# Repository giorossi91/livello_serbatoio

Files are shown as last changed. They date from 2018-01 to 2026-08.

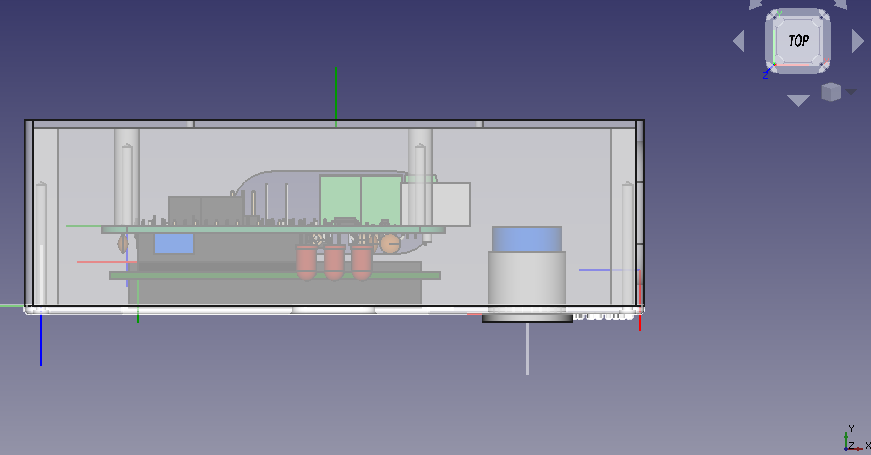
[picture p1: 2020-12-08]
schemi/scheda_definitiva/immagini/box_top.png

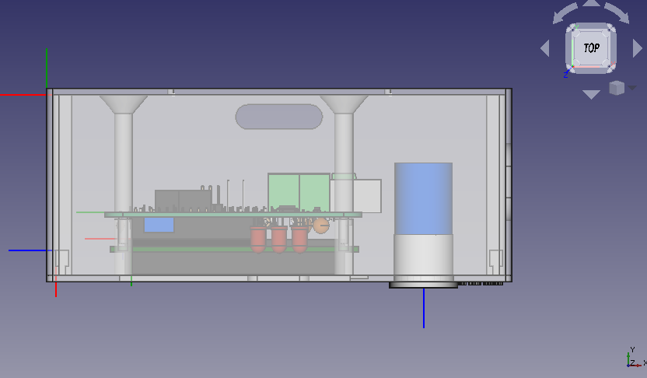
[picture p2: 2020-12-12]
schemi/box/senza_viti/img_senza_viti/box_top.png

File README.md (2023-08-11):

# Tank level monitor

## Scope
This project realizes a simple device to monitor the water level in a tank.

## Architecture
The monitor is realized with an ATMEGA328P microcontroller to run the SW produced with Arduino IDE environment, an ultrasonic sensor to measure the level of the water and an LCD 16x2 characters to show the liters amount associated to the percentage of filling.

## Sofware
The SW has been developed with Arduino IDE and tested with CppUnit and a Qt GUI used to simulate the external environment.

## Phases of the project
### Phase 1 (Prototype)
The project was realized on a prototype board using the schematic in `schemi\schema_scheda.pdf`. The microcontroller was hosted in an Arduino UNO rev3 board.
The schematic was realized with Fritzing. The enclosure was hand-made and adapted from an existing one.

### Phase 2 (Finished)
The entire schematic was re-designed with Kicad and a PCB has been designed and produced. The enclosure has been designed with Freecad and 3D printed.

## Project Website
Go to [project website](https://giorossi91.github.io/livello_serbatoio)

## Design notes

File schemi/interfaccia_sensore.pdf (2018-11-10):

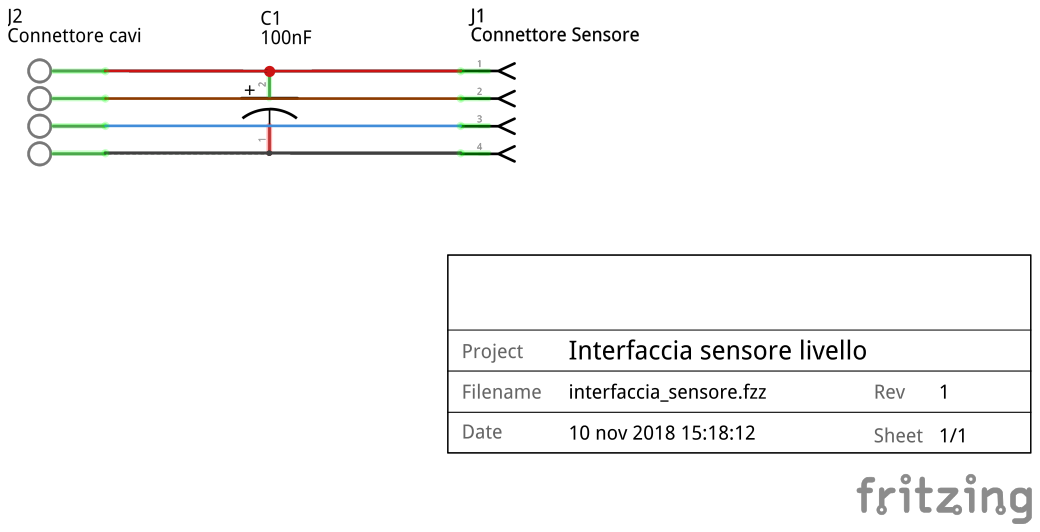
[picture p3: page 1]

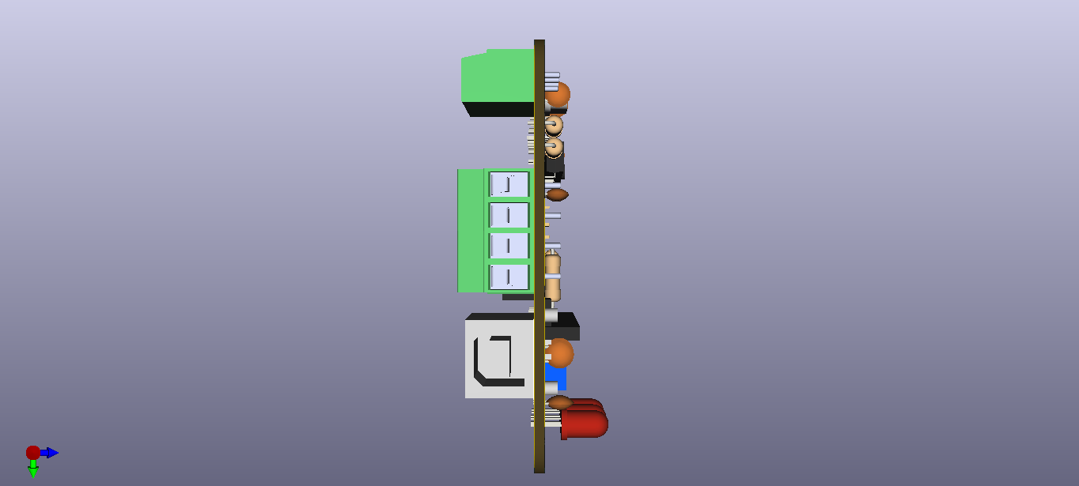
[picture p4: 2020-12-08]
schemi/scheda_definitiva/immagini/scheda_right.png

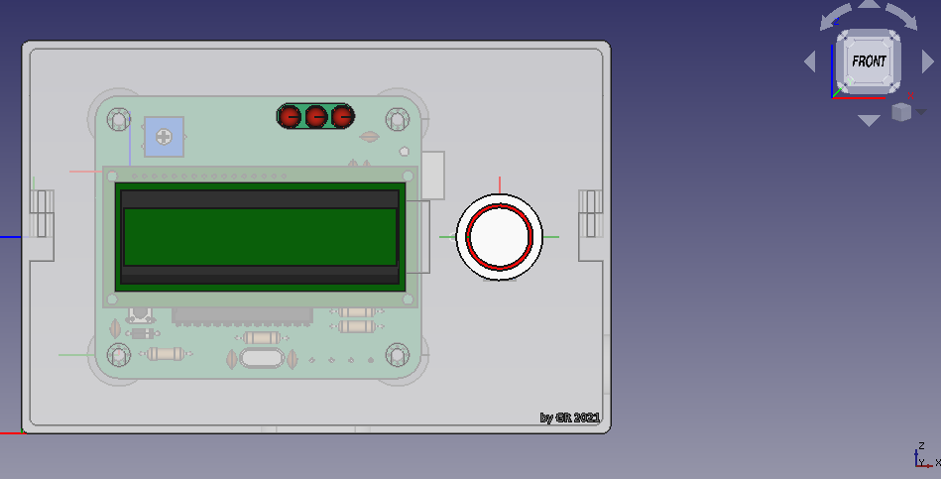
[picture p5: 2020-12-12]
schemi/box/senza_viti/img_senza_viti/box_front.png

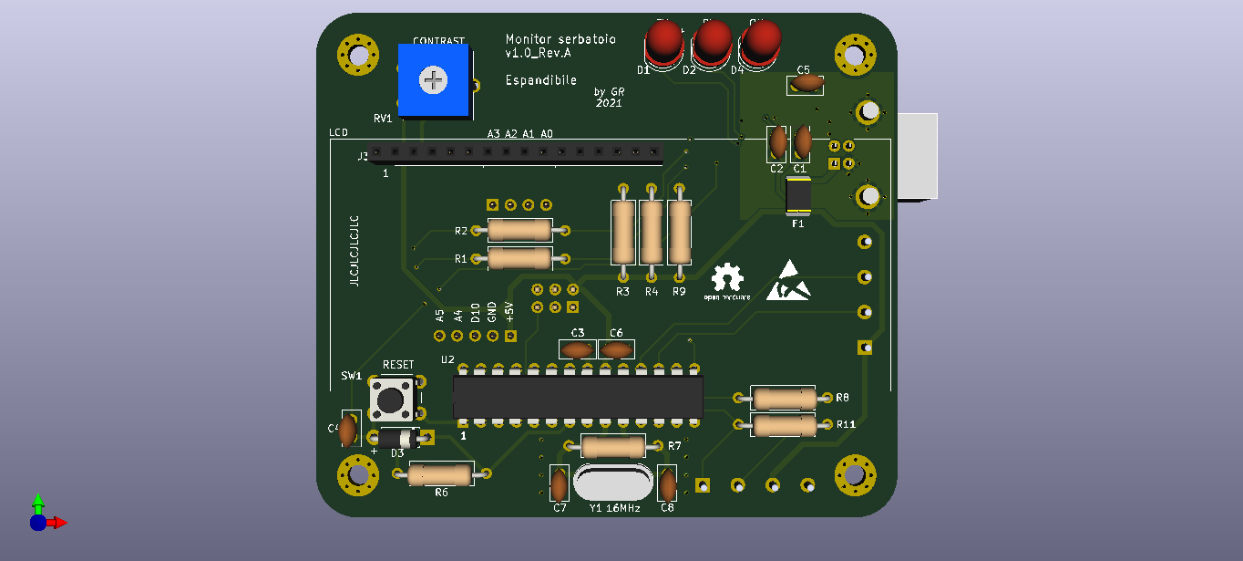
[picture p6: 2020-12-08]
schemi/scheda_definitiva/immagini/scheda_top.png

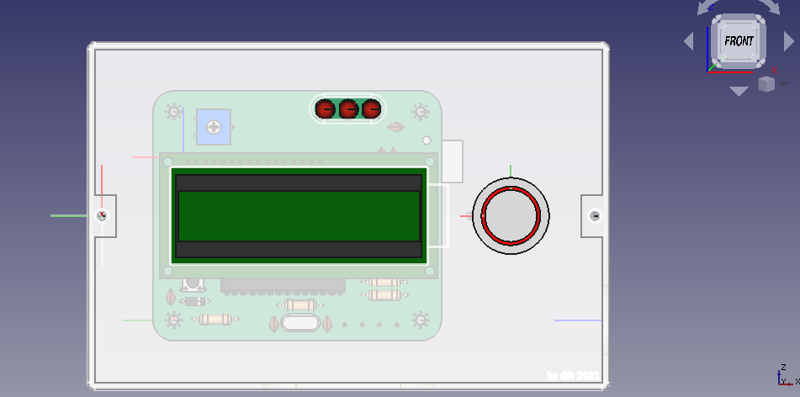
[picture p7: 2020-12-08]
schemi/scheda_definitiva/immagini/box_front.png

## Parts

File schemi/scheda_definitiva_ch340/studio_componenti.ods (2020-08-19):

Nome | Descrizione | Formato | Fornitore | Prezzo | Link | Note
FT232RL-REEL | Bridge Interfaccia, Da USB a UART, 1.8 V, 5.25 V, SSOP, 28 Pin, -40 °C | SSOP, 28 pin | Farnell | € 4,25 | https://it.farnell.com/ftdi/ft232rl-reel/ic-da-usb-a-uart-smd-28ssop/dp/1146032?st=ft232rl
ATMEGA328-PU | Microcontrollore a 8 bit, microcontrollori famiglia AVR ATmega, serie ATmega328, 20MHz, 1KB, 32KB | 28 PDIP | Farnell | € 1,70 | https://it.farnell.com/microchip/atmega328-pu/mcu-8bit-atmega-20mhz-dip-28/dp/1972087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
AS-16.000-18 | Cristallo, 16 MHz, Foro Passante, 10,3mm x 5mm, 50 ppm, 18 pF, 30 ppm, Serie AS | 5mm, foro passante 2 pin | Farnell | € 0,247 | https://it.farnell.com/raltron/as-16-000-18/cristallo-16mhz-18pf-hc-49s/dp/1611761?pf=412004278%2C412016994
1N4148TR | Diodo Piccolo Segnale, Singolo, 100 V, 150 mA, 1 V, 4 ns, 2 A | foro passante | Farnell | € 0,07 | https://it.farnell.com/vishay/1n4148tr/diodo-piccolo-segn-singolo-100v/dp/1469384
USB-B-S-RA | Connettore USB, USB Tipo B, USB 2.0, Presa, 4 Vie, Montaggio su Foro Passante, Angolo Retto | foro passante | Farnell | € 0,46 | https://it.farnell.com/multicomp/usb-b-s-ra/usb-2-0-tipo-b-presa-th/dp/2112373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
0473.500HAT1L | Fusibile, Cavo PCB, 500 mA, 125 V, PICO II 473 Series, 125 V, Azione Lenta, Conduttori Assiali | foro passante | Farnell | € 2,38 | https://it.farnell.com/littelfuse/0473-500hat1l/fusibile-assiale-0-5a-colpo-lento/dp/2723068?st=fuse
2227MC-28-03-05-F1 | Presa per CI e Componente, 28 Contatti, Presa DIP, 2.54 mm, Serie 2227MC, 7.62 mm, Bronzo Fosforoso | foro passante | Farnell | € 0,76 | https://it.farnell.com/multicomp/2227mc-28-03-05-f1/socket-ic-dil-0-3-28-vie/dp/1103850?MER=sy-me-pd-mi-alte

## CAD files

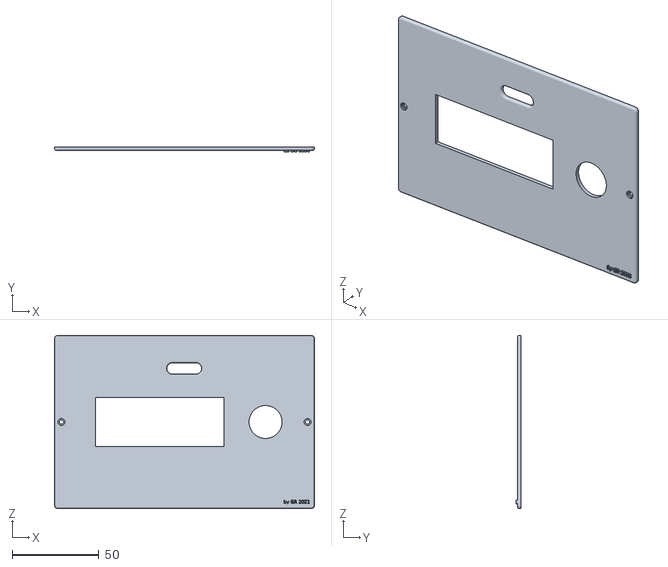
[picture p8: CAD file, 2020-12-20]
schemi/box/con_viti/coperchio_print.stl
150.0 x 3.00 x 100.0

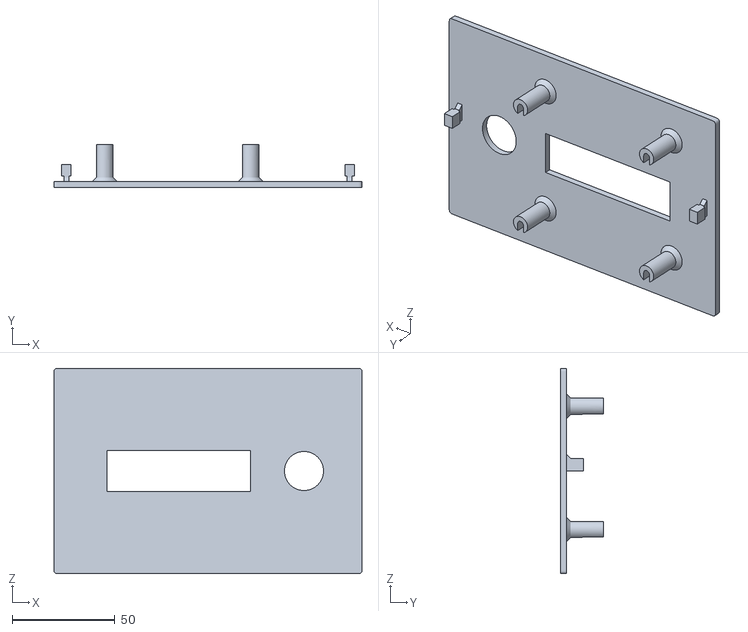
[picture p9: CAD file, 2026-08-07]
schemi/box/fusion360/Coperchio.stl
150.0 x 21.0 x 100.0

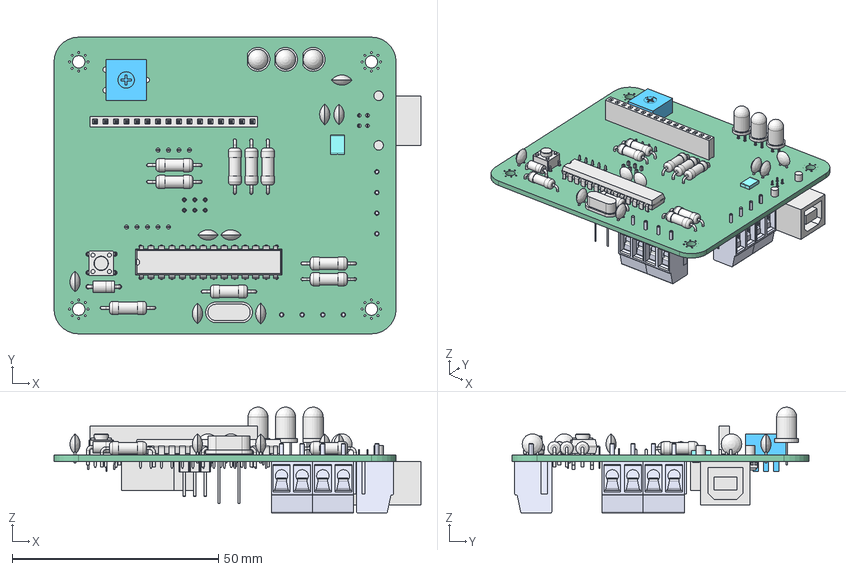
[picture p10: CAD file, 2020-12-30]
schemi/box/test_assembly_espansione/pcb_board.FCStd
89.0 x 72.0 x 25.7 mm
Pcb_8929
SW1_SW_PUSH_6mm_h5mm_5FCE63C8
RV1_ACP470_5F3BE09B x 2
D4_LED_D5.0mm_5FA6C0E4 x 3
F1_MF-MSMF050_5FB19120[2] x 2
D3_D_DO-41_SOD81_P7.62mm_Horizontal_5FCE6338
C5_C_Disc_D50mm_W25mm_P250mm_5FB07593 x 8
Y1_Crystal_5F93F8CD
U2_DIP-28_W7.62mm_5F8B1761
J3_PinSocket_1x16_P254mm_Vertical_5FB99047
R1_R_Axial_DIN0309_L90mm_D32mm_P1270mm_Horizontal_5FCA8AFD x 9
J6_PinSocket_1x04_P254mm_Vertical_5FCA8662
J7_PinSocket_1x05_P254mm_Vertical_5FC31174
U3_SOT_23_6_5FB065DB
TB001-500-02P_Green - P x 2
TB001-500-02P_Green - P001 x 2
J1_usb_b_conn_5FA8DFDA[2]
U1_SSOP_28_53x102mm_P065mm_5FB0862F
J5_PinHeader_2x03_P254mm_Vertical_5FA86B0F

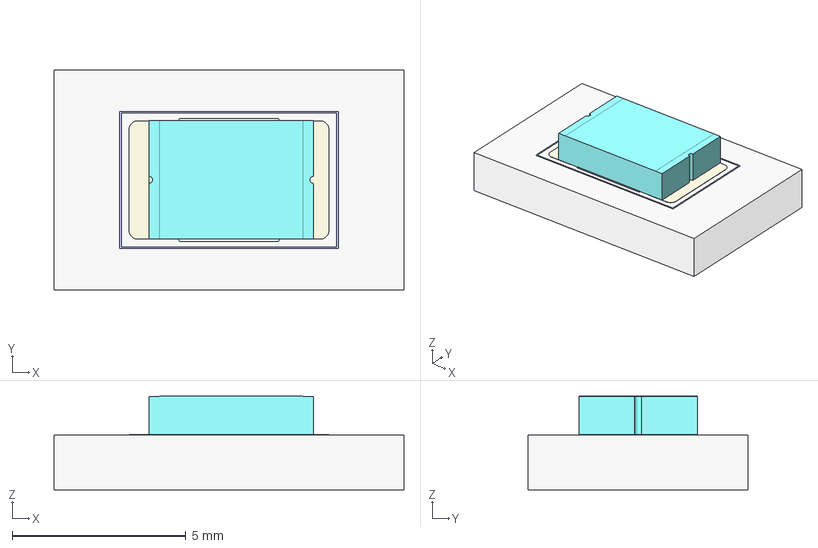
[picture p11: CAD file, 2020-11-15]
schemi/scheda_definitiva_ch340/3d_component/MF-MSMF050-2.FCStd
10.1 x 6.32 x 2.69 mm
FCrtYd
FFab
FrontSilk
TopPads
Pcb
MF-MSMF050

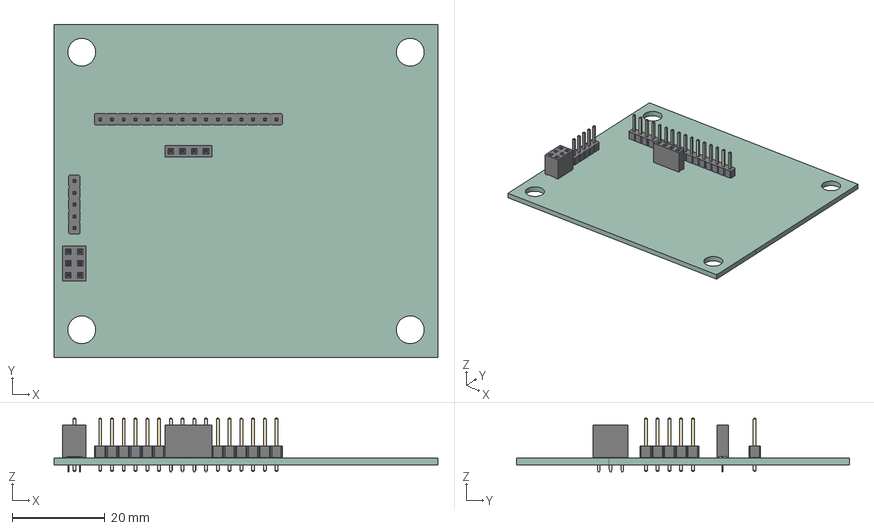
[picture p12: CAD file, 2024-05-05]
schemi/scheda_espansione/livello_serbatoio_espansione/livello_serbatoio_espansione.step
83.0 x 72.0 x 11.6 mm
PinSocket_2x03_P254mm_Vertical
PinHeader_1x16_P254mm_Vertical
PinHeader_1x05_P254mm_Vertical
PinSocket_1x04_P254mm_Vertical
livello_serbatoio_espansione_PCB

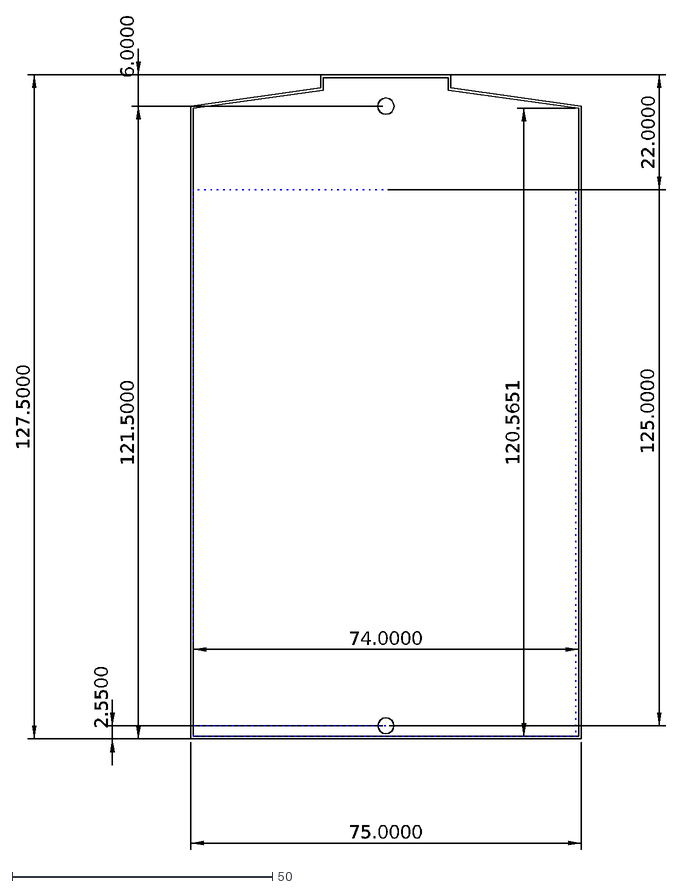
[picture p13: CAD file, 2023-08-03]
schemi/serbatoio.dxf
127.5000
121.5000
6.0000
2.5500
75.0000
120.5651
22.0000
74.0000
125.0000

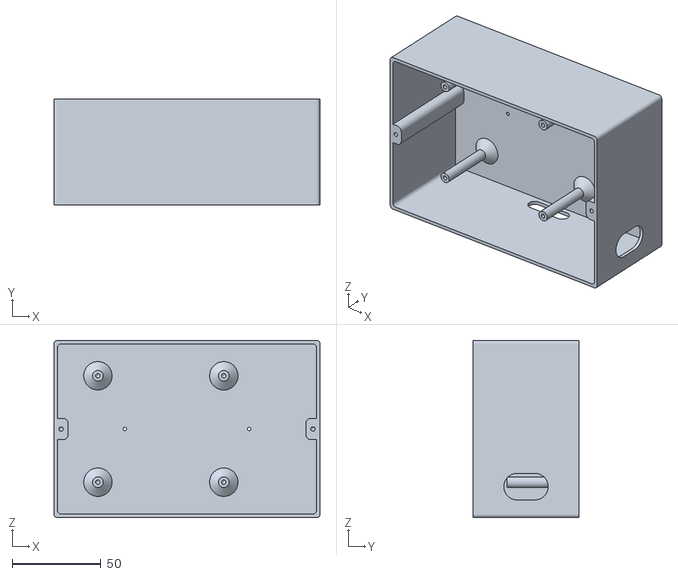
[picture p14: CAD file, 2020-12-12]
schemi/box/con_viti/box_print.stl
150.0 x 60.0 x 100.0

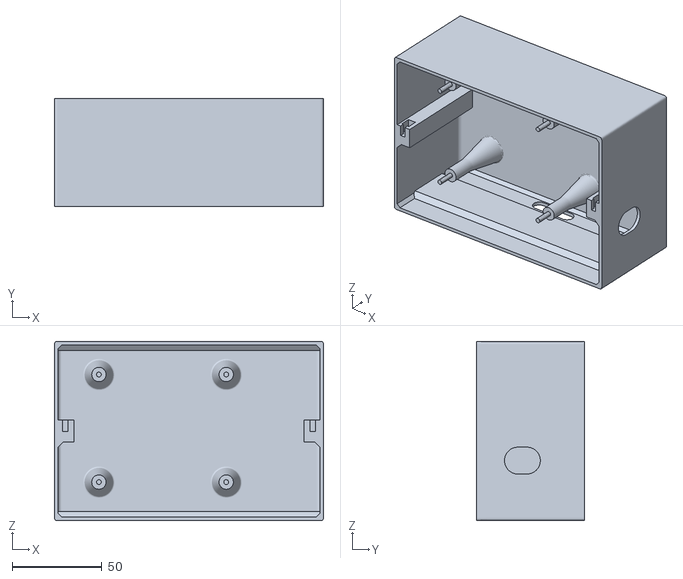
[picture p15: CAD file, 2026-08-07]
schemi/box/fusion360/Case.stl
150.0 x 60.0 x 100.0

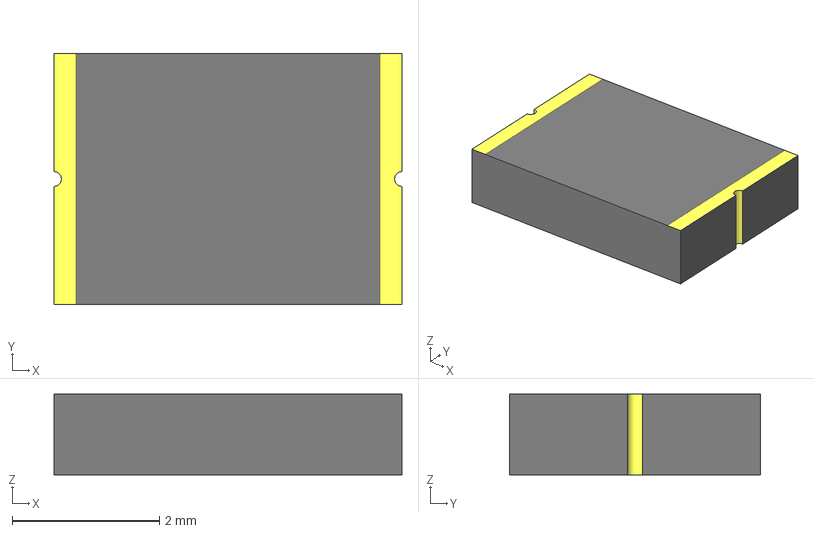
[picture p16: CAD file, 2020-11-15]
schemi/scheda_definitiva_ch340/3d_component/MF-MSMF050.step
4.73 x 3.41 x 1.10 mm

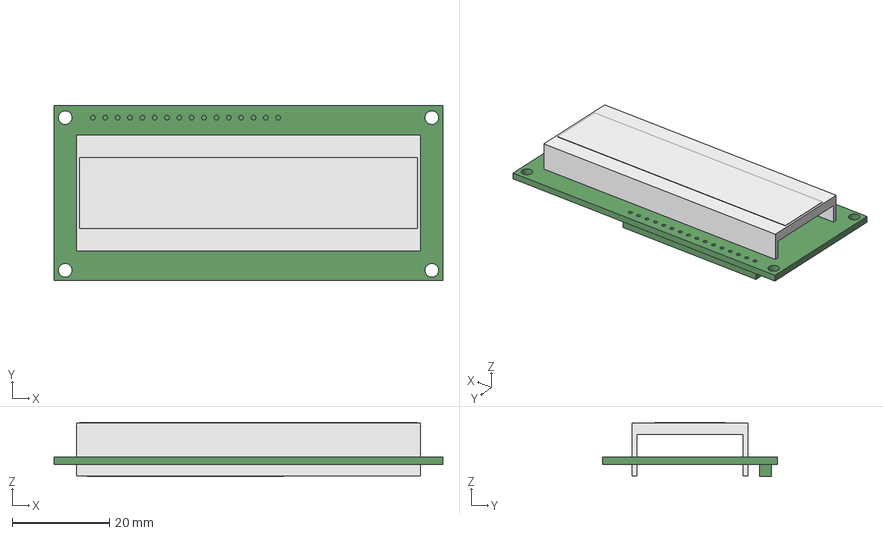
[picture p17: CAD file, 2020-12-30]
schemi/box/test_assembly_espansione/lcd.FCStd
80.0 x 36.0 x 11.2 mm
corpo_lcd
pcb
BooleanFragments

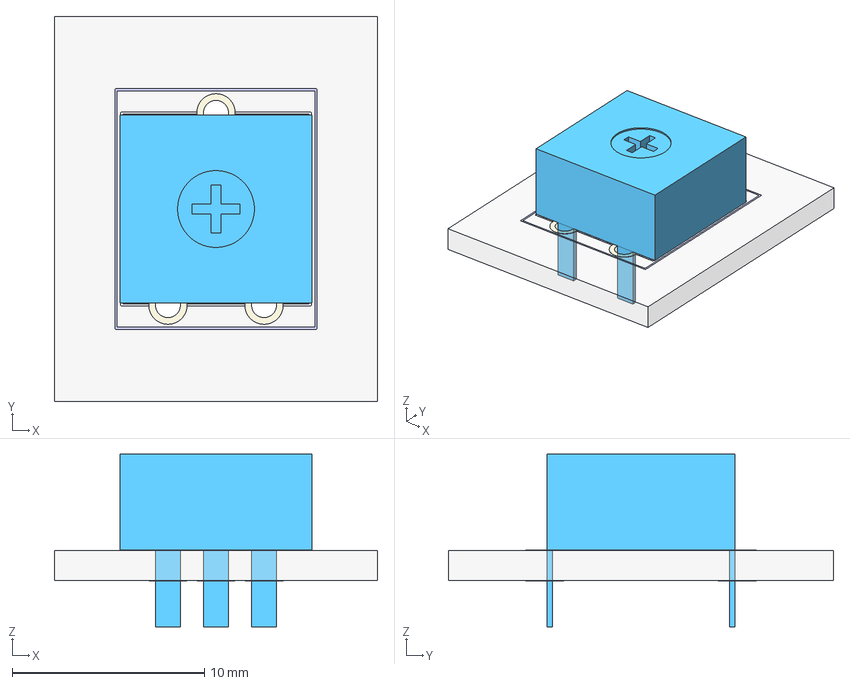
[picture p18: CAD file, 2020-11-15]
schemi/scheda_definitiva_ch340/3d_component/trimmer_acp470.FCStd
16.8 x 20.0 x 9.00 mm
FCrtYd
FrontSilk
TopPads
BotPads
PTHs
Pcb
ACP470

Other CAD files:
schemi/box/senza_viti/assembly.FCStd
schemi/box/test_assembly_espansione/assembly_exp.FCStd
schemi/box/con_viti/assembly.FCStd
schemi/box/senza_viti/pcb_board.FCStd
schemi/box/test_assembly_espansione/box_part.FCStd
schemi/box/con_viti/pcb_board.FCStd
schemi/box/senza_viti/box_print.stl
schemi/box/con_viti/box_part.FCStd
schemi/box/con_viti/coperchio.FCStd
schemi/box/con_viti/lcd.FCStd
schemi/box/con_viti/push_button.FCStd
schemi/box/senza_viti/coperchio_print.stl
schemi/box/test_assembly_espansione/coperchio.FCStd
schemi/box/test_assembly_espansione/pcb_expansion.FCStd
schemi/box/test_assembly_espansione/push_button.FCStd
schemi/scheda_definitiva_ch340/3d_component/ACP470.step
schemi/scheda_definitiva_ch340/3d_component/CUI_DEVICES_TB001-500-P04GR.step
schemi/scheda_definitiva_ch340/3d_component/Crystal.step
schemi/scheda_definitiva_ch340/3d_component/crystal.FCStd
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

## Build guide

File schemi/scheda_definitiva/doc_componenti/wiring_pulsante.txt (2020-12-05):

LED 
 Verde positivo
 Giallo Negativo
 
Pulsante
 Blu + Nero (Normalmente aperto)

 Rosso + Nero (Normalmente chiuso)

 Nero (Comune)

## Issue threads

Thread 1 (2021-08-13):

Display non rimane acceso in debug

giorossi91, 2021-08-13:
https://github.com/giorossi91/livello_serbatoio/blob/063046ad914f6690e44554796f7b9f534d8bcf51/livello_serbatoio.ino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

Quando si entra in debug mode, il display non rimane acceso per il tempo programmato, ma si spegne immediatamente.

Closed 2023-08-11.

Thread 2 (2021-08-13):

Miglioramento box e coperchio

giorossi91, 2021-08-13:
### Coperchio
Al coperchio va tolta l'asola dei led perché esteticamente brutta e lascia passare troppa luce.

### Box
Il box va rinforzato meccanicamente ai lati superiore ed inferiore per evitare che si deformi con la stampa 3D.

Inoltre il box andrebbe leggermente allargato in senso orizzontale per fare entrare meglio il cavo USB B che risulta troppo piegato.

giorossi91, 2024-04-26:
Rifatto progetto su Fusion360. Eseguiti i miglioramenti indicati in questa issue.

Closed 2024-04-26.

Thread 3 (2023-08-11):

Blocco avvio in caso di lettura sotto soglia minima

giorossi91, 2023-08-11:
Quando si accende il sistema, se il sensore rileva una lettura sotto soglia minima (da verificare) succede che il display rimane sulla schermata "Prima lettura..." ed il pulsante continua a lampeggiare.

giorossi91, 2024-08-26:
Non è riproducibile in ambiente simulato né si è più verificato su scheda vera. Rimane monitorato.

Closed 2024-08-26.

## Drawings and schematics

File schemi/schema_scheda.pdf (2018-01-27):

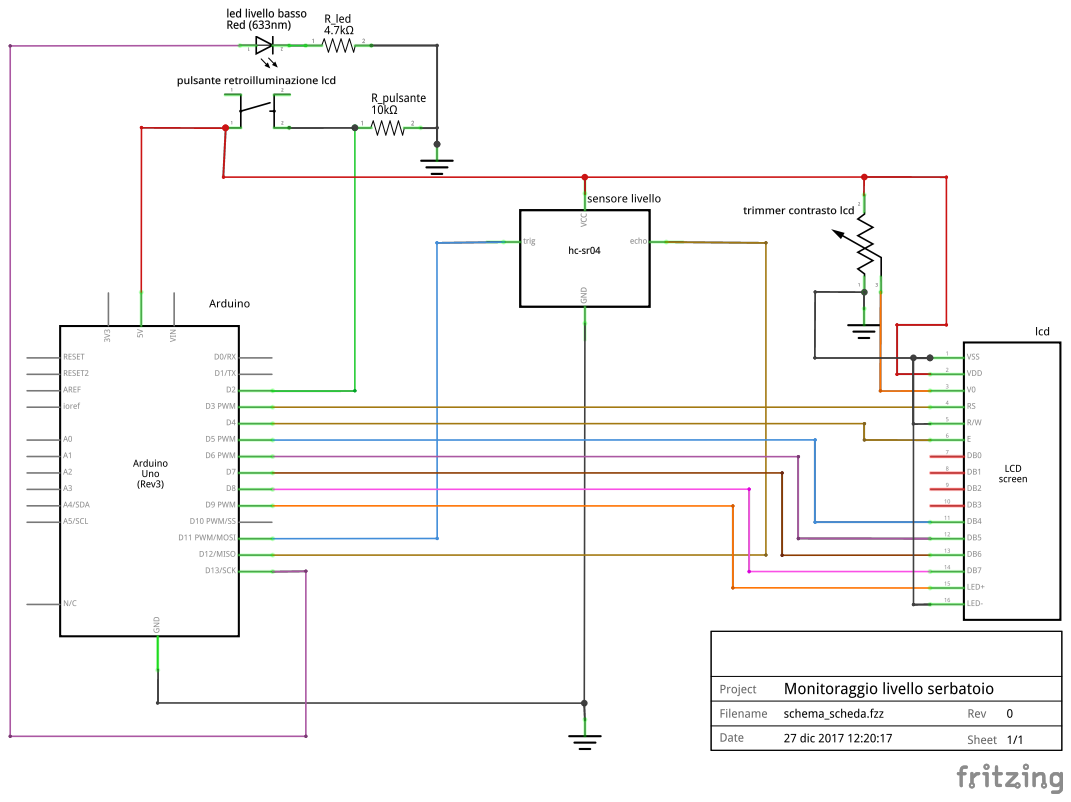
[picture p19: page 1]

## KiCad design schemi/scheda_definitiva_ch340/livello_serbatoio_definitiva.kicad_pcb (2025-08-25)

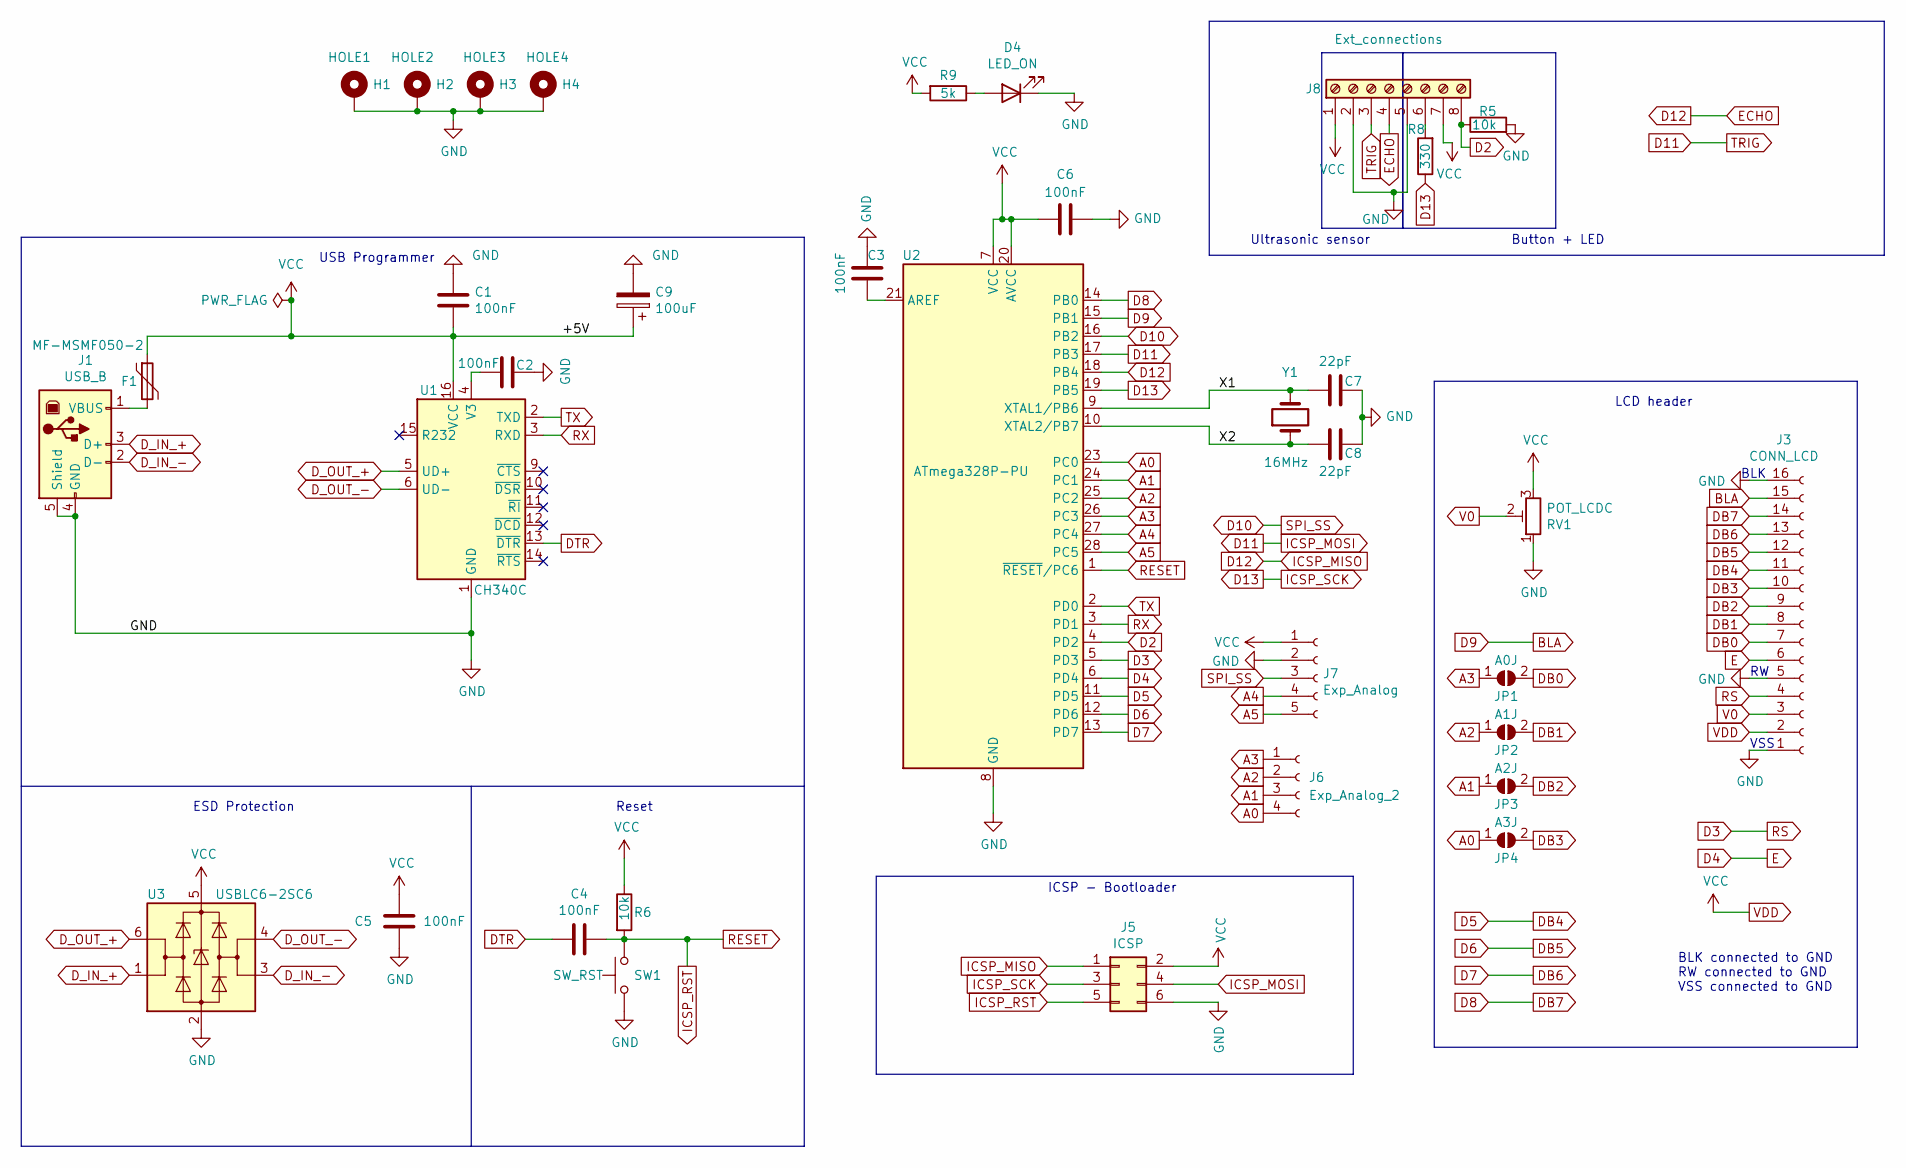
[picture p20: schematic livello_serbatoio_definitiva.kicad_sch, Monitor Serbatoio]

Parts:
C1, C2, C3, C4, C5, C6: 100nF; C_Disc_D5.0mm_W2.5mm_P2.50mm
C7, C8: 22pF; C_Disc_D5.0mm_W2.5mm_P2.50mm
C9: 100uF; CP_Radial_D5.0mm_P2.00mm
D4: LED_ON; LED_D5.0mm
F1: MF-MSMF050-2; MF-MSMF_1812_4532Metric_Pad1.30x3.40mm_HandSolder
H1: HOLE1; MountingHole_3mm_Pad_Via
H2: HOLE2; MountingHole_3mm_Pad_Via
H3: HOLE3; MountingHole_3mm_Pad_Via
H4: HOLE4; MountingHole_3mm_Pad_Via
J1: USB_B; USB_B_OST_USB-B1HSxx_Horizontal
J3: CONN_LCD; PinSocket_1x16_P2.54mm_Vertical
J5: ICSP; PinHeader_2x03_P2.54mm_Vertical
J6: Exp_Analog_2; PinSocket_1x04_P2.54mm_Vertical
J7: Exp_Analog; PinSocket_1x05_P2.54mm_Vertical
J8: Ext_connections; TerminalBlock_RND_205-00051_1x08_P5.00mm_Horizontal
JP1: A0J; SolderJumper-2_P1.3mm_Open_Pad1.0x1.5mm
JP2: A1J; SolderJumper-2_P1.3mm_Open_Pad1.0x1.5mm
JP3: A2J; SolderJumper-2_P1.3mm_Open_Pad1.0x1.5mm
JP4: A3J; SolderJumper-2_P1.3mm_Open_Pad1.0x1.5mm
R5, R6: 10k; R_Axial_DIN0309_L9.0mm_D3.2mm_P12.70mm_Horizontal
R8: 330; R_Axial_DIN0309_L9.0mm_D3.2mm_P12.70mm_Horizontal
R9: 5k; R_Axial_DIN0309_L9.0mm_D3.2mm_P12.70mm_Horizontal
RV1: POT_LCDC; Trimmer_ACP_470
SW1: SW_RST; SW_PUSH_6mm_H5mm
U1: CH340C; SOIC-16_3.9x9.9mm_P1.27mm
U2: ATmega328P-PU; DIP-28_W7.62mm
U3: USBLC6-2SC6; SOT-23-6_Handsoldering
Y1: 16MHz; Crystal_TH_AS16_5mm

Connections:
/X1: C7.2, U2.9 (XTAL1/PB6), Y1.2
/X2: C8.2, U2.10 (XTAL2/PB7), Y1.1
A0: J6.4, JP4.1 (A), U2.23 (PC0)
A1: J6.3, JP3.1 (A), U2.24 (PC1)
A2: J6.2, JP2.1 (A), U2.25 (PC2)
A3: J6.1, JP1.1 (A), U2.26 (PC3)
A4: J7.4, U2.27 (PC4)
A5: J7.5, U2.28 (PC5)
BLA: J3.15, U2.15 (PB1)
D2: J8.8, R5.1, U2.4 (PD2)
D3: J3.4, U2.5 (PD3)
D4: J3.6, U2.6 (PD4)
D5: J3.11, U2.11 (PD5)
D6: J3.12, U2.12 (PD6)
D7: J3.13, U2.13 (PD7)
D8: J3.14, U2.14 (PB0)
D10: J7.3, U2.16 (PB2)
D11: J5.4, J8.3, U2.17 (PB3)
D12: J5.1, J8.4, U2.18 (PB4)
D13: J5.3, R8.1, U2.19 (PB5)
DB0: J3.7, JP1.2 (B)
DB1: J3.8, JP2.2 (B)
DB2: J3.9, JP3.2 (B)
DB3: J3.10, JP4.2 (B)
DTR: C4.2, U1.13 (~DTR)
D_IN_+: J1.3 (D+), U3.1 (I/O1)
D_IN_-: J1.2 (D-), U3.3 (I/O2)
D_OUT_+: U1.5 (UD+), U3.6 (I/O1)
D_OUT_-: U1.6 (UD-), U3.4 (I/O2)
GND: C1.1, C2.2, C3.2, C5.1, C6.2, C7.1, C8.1, C9.2, D4.1 (K), H1.1, H2.1, H3.1, H4.1, J1.4 (GND), J1.5 (Shield), J3.1, J3.5, J3.16, J5.6, J7.2, J8.2, J8.5, R5.2, RV1.1, SW1.1, U1.1 (GND), U2.8 (GND), U2.22 (GND), U3.2 (GND)
ICSP_RST: C4.1, J5.5, R6.2, SW1.2, U2.1 (~RESET/PC6)
unnamed: D4.2 (A), R9.1
unnamed: F1.2, J1.1 (VBUS)
unnamed: J8.6, R8.2
unnamed: C2.1, U1.4 (V3)
unnamed: C3.1, U2.21 (AREF)
RX: U1.3 (RXD), U2.3 (PD1)
TX: U1.2 (TXD), U2.2 (PD0)
V0: J3.3, RV1.2
VDD: C1.2, C5.2, C6.1, C9.1, F1.1, J3.2, J5.2, J7.1, J8.1, J8.7, R6.1, R9.2, RV1.3, U1.16 (VCC), U2.7 (VCC), U2.20 (AVCC), U3.5 (VBUS)

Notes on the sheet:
ESD Protection
BLK
Reset
USB Programmer
Ultrasonic sensor
BLK connected to GND RW connected to GND VSS connected to GND
VSS
Button + LED
ICSP - Bootloader
LCD header

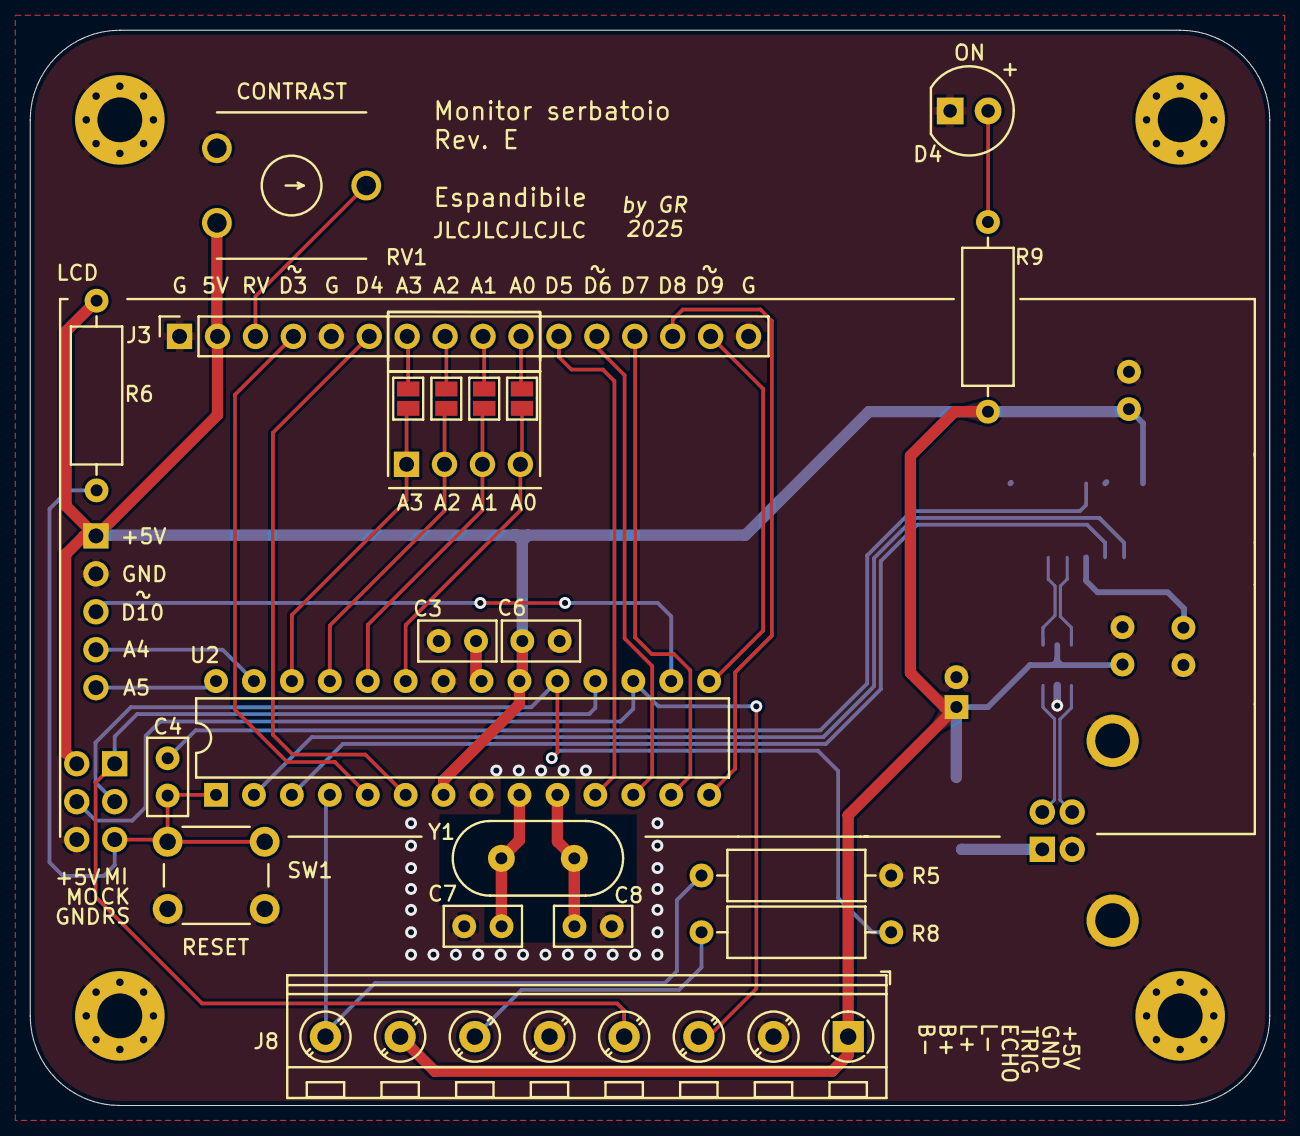
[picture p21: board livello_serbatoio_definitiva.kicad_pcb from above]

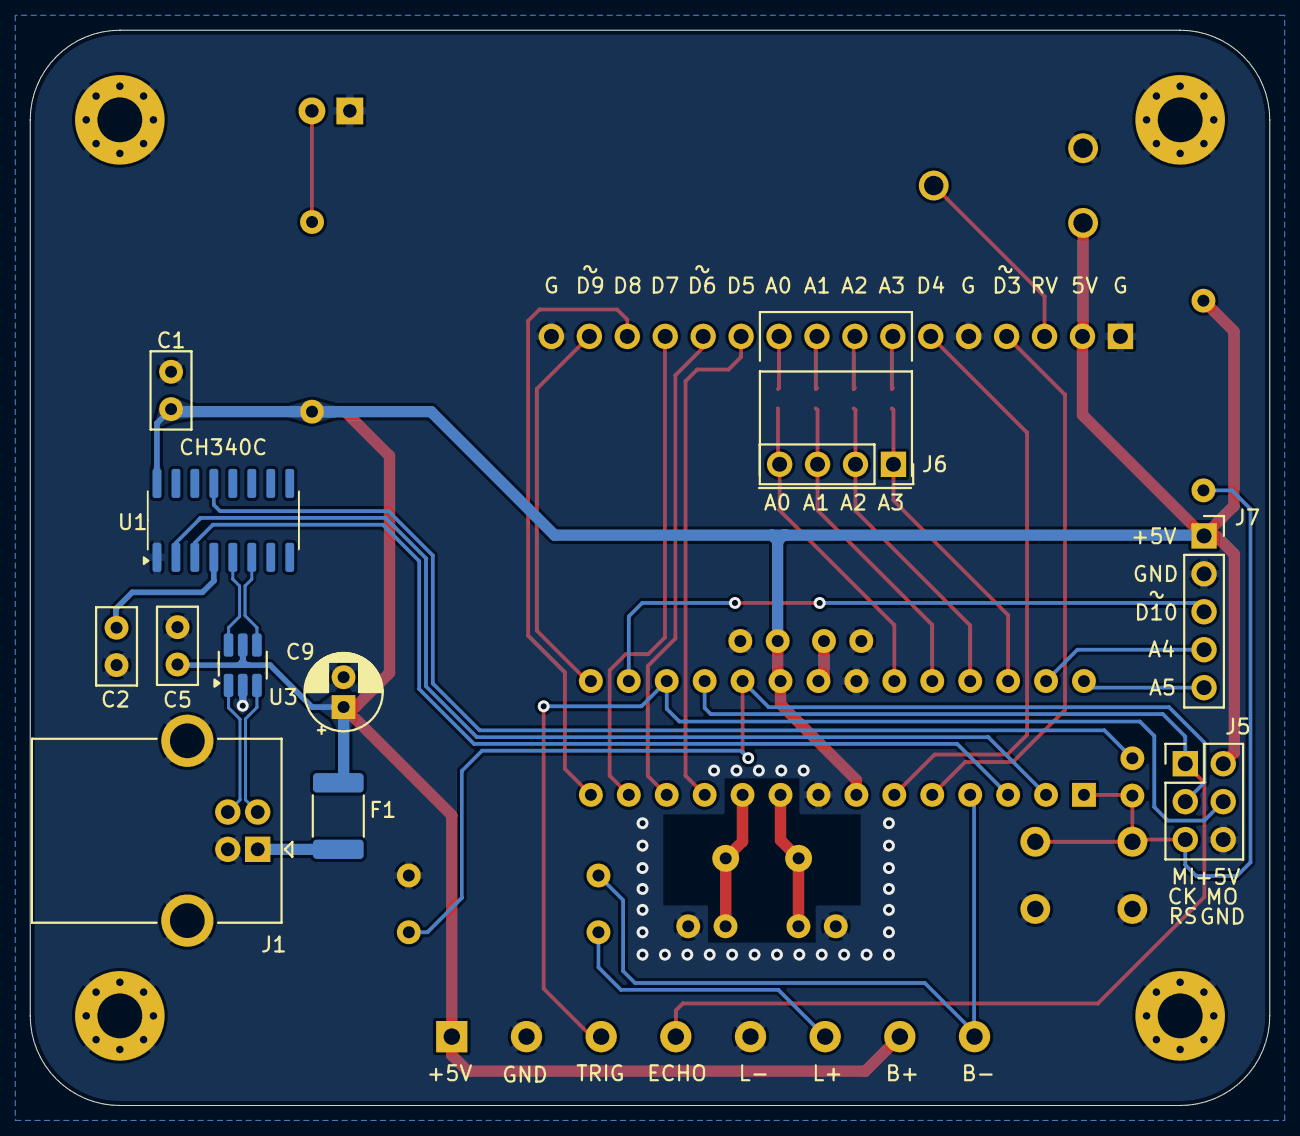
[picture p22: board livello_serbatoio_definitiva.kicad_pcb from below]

Board: 2 copper layers, 83.0 x 72.0 mm, 35 parts (11 on the bottom side), 40 nets.

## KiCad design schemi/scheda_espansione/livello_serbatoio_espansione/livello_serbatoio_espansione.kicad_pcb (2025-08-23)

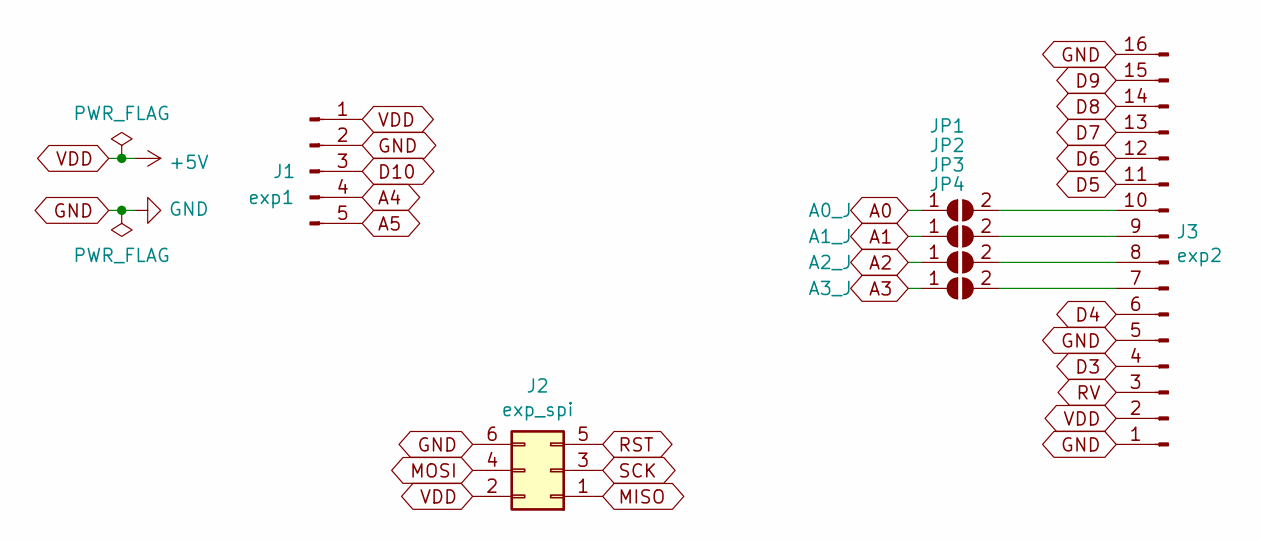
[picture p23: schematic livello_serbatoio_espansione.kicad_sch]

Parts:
J1: exp1; PinHeader_1x05_P2.54mm_Vertical
J2: exp_spi; PinSocket_2x03_P2.54mm_Vertical
J3: exp2; PinHeader_1x16_P2.54mm_Vertical
JP1: A0_J; SolderJumper-2_P1.3mm_Open_Pad1.0x1.5mm
JP2: A1_J; SolderJumper-2_P1.3mm_Open_Pad1.0x1.5mm
JP3: A2_J; SolderJumper-2_P1.3mm_Open_Pad1.0x1.5mm
JP4: A3_J; SolderJumper-2_P1.3mm_Open_Pad1.0x1.5mm

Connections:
A0: JP1.1 (A); also elsewhere on the board
A1: JP2.1 (A); also elsewhere on the board
A2: JP3.1 (A); also elsewhere on the board
A3: JP4.1 (A); also elsewhere on the board
A4: J1.4
A5: J1.5
D3: J3.4
D4: J3.6
D5: J3.11
D6: J3.12
D7: J3.13
D8: J3.14
D9: J3.15
D10: J1.3
GND: J1.2, J2.6, J3.1, J3.5, J3.16
MISO: J2.1
MOSI: J2.4
unnamed: J3.7, JP4.2 (B)
unnamed: J3.8, JP3.2 (B)
unnamed: J3.9, JP2.2 (B)
unnamed: J3.10, JP1.2 (B)
RST: J2.5
RV: J3.3
SCK: J2.3
VDD: J1.1, J2.2, J3.2

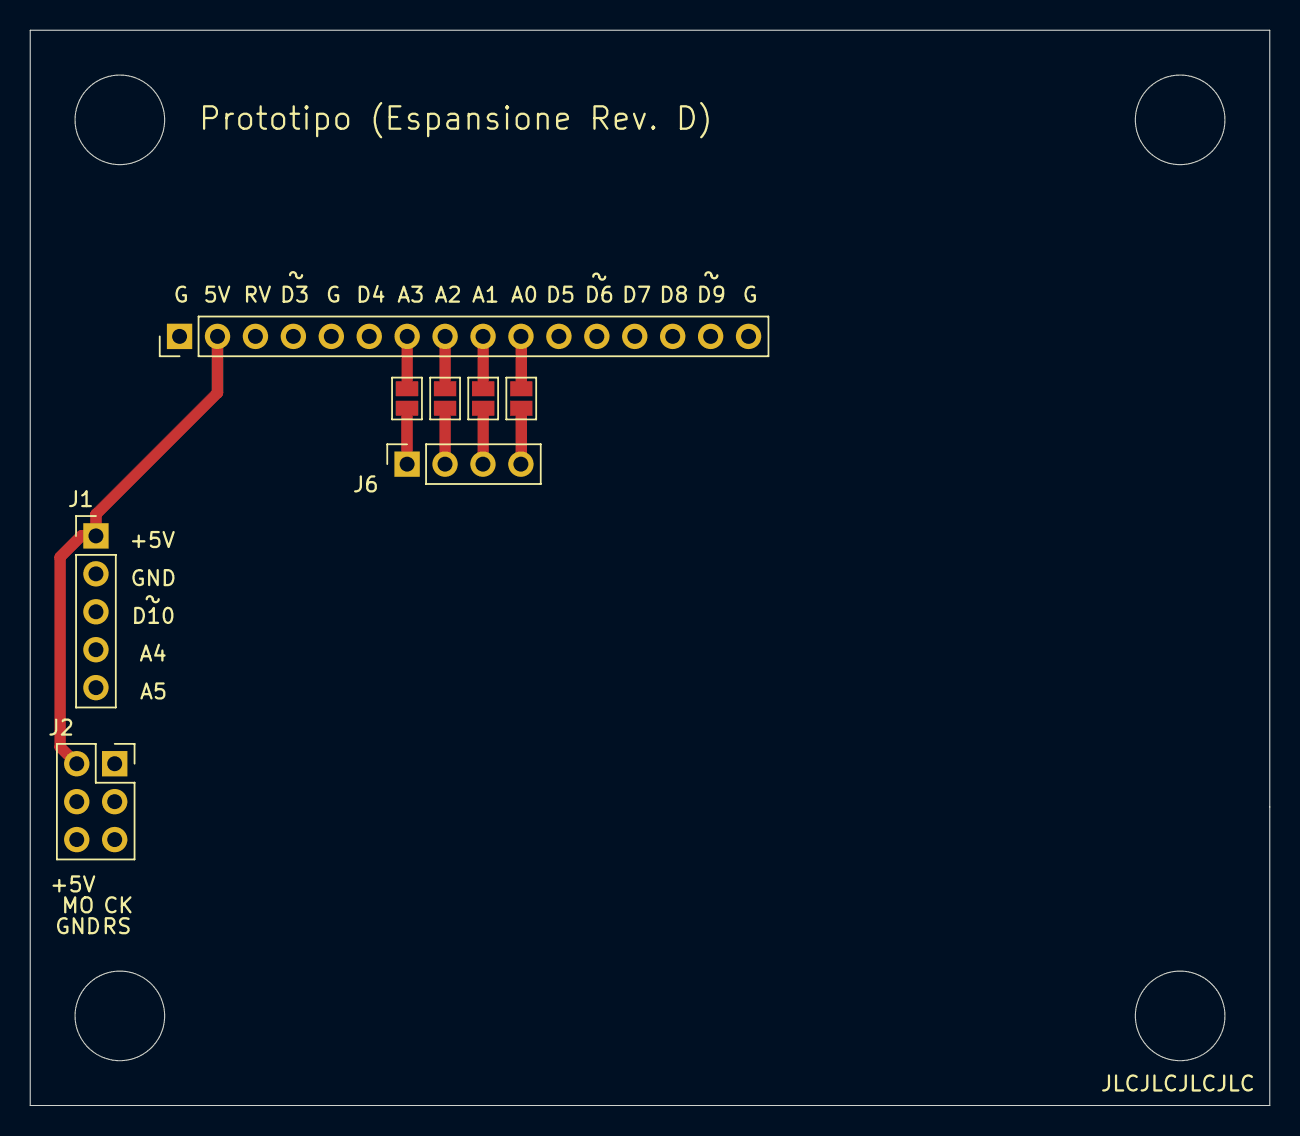
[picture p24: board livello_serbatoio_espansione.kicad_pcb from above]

Board: 2 copper layers, 83.0 x 72.0 mm, 8 parts (0 on the bottom side), 10 nets.

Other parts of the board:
J6: Exp_Analog_2; PinSocket_1x04_P2.54mm_Vertical

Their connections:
A0: J6.4; also elsewhere on the board
A1: J6.3; also elsewhere on the board
A2: J6.2; also elsewhere on the board
A3: J6.1; also elsewhere on the board

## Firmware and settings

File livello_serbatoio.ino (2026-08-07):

//!
//! \brief Software for water tank level monitoring.
//!
//! \details This Software measures and monitors the water level in a tank using an ultrasonic distance sensor.
//!          It shows essential information (such as remaining liters and fill percentage) in a 16x2 LCD and 
//!          warns about low water level using a LED.
//!
//!          Pinout and links:
//!          - LCD (1602A):
//!            - Vss  : GND
//!            - Vdd  : +5V
//!            - Vo   : OUT Potentiometer (for contrast regulation)
//!            - RS   : DIGITAL 12
//!            - RW   : GND (Write)
//!            - E    : DIGITAL 11
//! 
//!            - DB4, DB5, DB6, DB7
//!            -   4 ,  5 ,  6 ,  7  (DIGITAL)
//!
//!
//! \author Giovanni Rossi
//!
//! \copyright This project is released under the GNU General Public License v3.0.
//!

// Includes
#ifndef UNIT_TEST
#include <LiquidCrystal.h>
#endif

// Defines
#define VERSION "v0.14"    //!< Version tag
#define BANNER  "GR26"     //!< Author and year of build

#define CONF_DEBUG   1    //!< Constant used to compile in DEBUG mode (Serial enabled).
#define CONF_RELEASE 0    //!< Constant used to compile in RELEASE mode (Serial disabled).

#define SENSOR_HCSR04   0 //!< Constant used to compile code for HC-SR04 ultrasonic sensor.
#define SENSOR_JSNSR04T 1 //!< Constant used to compile code for JSN-SR04T ultrasonic sensor (waterproof).

// Configuration
#ifndef UNIT_TEST
# define DEBUG  CONF_DEBUG   //!< Current configuration
# define SENSOR SENSOR_HCSR04  //!< Current sensor
#endif

///
/// \defgroup TypesGroup Custom types
/// @{
typedef double float64_t;
/// @}

///
/// \defgroup ConstGroup Constants
/// @{

///
/// \defgroup MedFilterGroup Median filter
/// @{
const int16_t     FILTER_SEED           = 0                                   ; //!< Initial value for Median Filter.
const int16_t     FILTER_SIZE           = 5                                   ; //!< Median Filter size.
/// @}

///
/// \defgroup PinGroup Pins used
/// @{
const int16_t     ECHO_DPIN             = 12                                  ; //!< Digital pin for ultrasonic sensor ECHO pin.
const int16_t     TRIG_DPIN             = 11                                  ; //!< Digital pin for ultrasonic sensor TRIG pin.
const int16_t     LED_CAPACITY_DPIN     = 13                                  ; //!< Digital pin for LED.
const int16_t     LCD_BUTTON_DPIN       = 2                                   ; //!< Digital pin for Button.
const int16_t     LCD_LIGHT_DPIN        = 9                                   ; //!< Digital pin for LCD backlight.
/// @}

///
/// \defgroup TankGroup Tank and volume
/// @{
const uint16_t    TANK_NUMBER           = 2U                                  ; //!< The number of tanks.
const float64_t   TANK_RADIUS_CM        = 65.0 / 2.0                          ; //!< The radius of the tank(s) in cm.
const float64_t   TANK_HEIGHT_CM        = 150.0                               ; //!< The height of the tank(s) in cm.
const float64_t   SENSOR_DISTANCE_CM    = 19.0                                ; //!< The distance between sensor and the highest water level in cm.
const float64_t   WATER_MAX_HEIGHT_CM   = TANK_HEIGHT_CM - SENSOR_DISTANCE_CM ; //!< The maximum water height in cm.
const float64_t   LOW_LEVEL_THRESHOLD   = 40.0                                ; //!< The percentage threshold used to indicate the low level of water.
const float64_t   EMPTY_LEVEL_THRESHOLD = 20.0                                ; //!< The percentage threshold used to indicate the tank(s) emptiness.
/// @}

///
/// \defgroup ConversionGroup Conversion units
/// @{
const float64_t   CM3_PER_LITER         = 1000.0                              ; //!< Constant used to convert liters in cm^3 (1 l = 1000 cm^3).
/// @}

///
/// \defgroup TimerGroup Timers constants
/// @{
const uint32_t    MEASURE_LF_INTERVAL   = 30 * 1000                           ; //!< Inteval between two measurements (low frequency) in milliseconds.
const uint32_t    MEASURE_HF_INTERVAL   =  5 * 1000                           ; //!< Inteval between two measurements (high frequency) in milliseconds.
const uint32_t    LCD_ON_TIME           = 30 * 1000                           ; //!< LCD backlight duration in milliseconds.
const uint32_t    SLEEP_TIME            =  100                                ; //!< Sleep time between two execution of #loop in milliseconds.
const uint32_t    SHOW_STAT_TIME        = 5000                                ; //!< Duration for visualization of Statistics in milliseconds.
const uint32_t    SHOW_PARAM_TIME       = 5000                                ; //!< Duration for visualization of Tank Parameters in milliseconds.
const uint32_t    SHOW_VERSION_TIME     = 3000                                ; //!< Duration for visualization of SW Version in milliseconds.
const uint32_t    LED_CONTROL_TIME      = 1000                                ; //!< Period of LED blinking in milliseconds.
const uint32_t    READ_DISTANCE_TIME    = 1000                                ; //!< Period of distance reading from Median Filter in milliseconds.
const uint32_t    BTN_INTERVAL_1_TIME   =  200                                ; //!< Duration to trig Slot 1 of menu in milliseconds.
const uint32_t    BTN_INTERVAL_2_TIME   = 2000                                ; //!< Duration to trig Slot 2 of menu in milliseconds.
const uint32_t    BTN_INTERVAL_3_TIME   = 3000                                ; //!< Duration to trig Slot 3 of menu in milliseconds.
const uint32_t    BTN_INTERVAL_4_TIME   = 4000                                ; //!< Duration to trig Slot 4 of menu in milliseconds.
const uint32_t    BTN_INTERVAL_5_TIME   = 5000                                ; //!< Duration to trig Slot 5 of menu in milliseconds.
const uint32_t    BTN_INTERVAL_6_TIME   = 6000                                ; //!< Duration to trig Slot 6 of menu in milliseconds.
/// @}

///
/// \defgroup SensorGroup Sensor parameters
/// Constants related to the ultrasonic sensors.
/// @{
#if SENSOR == SENSOR_JSNSR04T

const float64_t   SENSOR_CALIBRATION    = 1.7                                 ; //!< Sensor distance offset used for calibration in centimeters.
const float64_t   SENSOR_MIN_RANGE      = 20.0                                ; //!< Sensor minimum readable distance in centimeters.
const float64_t   SENSOR_MAX_RANGE      = 600.0                               ; //!< Sensor maximum readable distance in centimeters.
const float64_t   SENSOR_LSB            = 58.0                                ; //!< Sensor LSB to achieve distance from ECHO pulse time in usec/cm.
const int32_t     SENSOR_ACTIVATION_TH  = 15                                  ; //!< Duration of TRIG signal to perform a measurement.

const uint32_t    SENSOR_RESPONSE_TIMEOUT_US = 500000UL                       ; //!< Timeout in microseconds used to determine when the sensor reading is failed.
const uint32_t    SENSOR_NO_OBSTACLE_US      = 38000UL                        ; //!< ECHO pulse time in microseconds which indicates the absence of sensor readable obstacles.

#elif SENSOR == SENSOR_HCSR04

const float64_t   SENSOR_CALIBRATION    = 1.0                                 ; //!< Sensor distance offset used for calibration in centimeters.
const float64_t   SENSOR_MIN_RANGE      = 2.0                                 ; //!< Sensor minimum readable distance in centimeters.
const float64_t   SENSOR_MAX_RANGE      = 450.0                               ; //!< Sensor maximum readable distance in centimeters.
const float64_t   SENSOR_LSB            = 58.0                                ; //!< Sensor LSB to achieve distance from ECHO pulse time in usec/cm.
const int32_t     SENSOR_ACTIVATION_TH  = 15                                  ; //!< Duration of TRIG signal to perform a measurement.

const uint32_t    SENSOR_RESPONSE_TIMEOUT_US = 500000UL                       ; //!< Timeout in microseconds used to determine when the sensor reading is failed.
const uint32_t    SENSOR_NO_OBSTACLE_US      = 38000UL                        ; //!< ECHO pulse time in microseconds which indicates the absence of sensor readable obstacles.

#else

const float64_t   SENSOR_CALIBRATION    = 0.0                                 ; //!< Sensor distance offset used for calibration in centimeters.
const float64_t   SENSOR_MIN_RANGE      = 0.0                                 ; //!< Sensor minimum readable distance in centimeters.
const float64_t   SENSOR_MAX_RANGE      = 0.0                                 ; //!< Sensor maximum readable distance in centimeters.
const float64_t   SENSOR_LSB            = 1.0                                 ; //!< Sensor LSB to achieve distance from ECHO pulse time in usec/cm.
const int32_t     SENSOR_ACTIVATION_TH  = 15                                  ; //!< Duration of TRIG signal to perform a measurement.

const uint32_t    SENSOR_RESPONSE_TIMEOUT_US = 500000UL                       ; //!< Timeout in microseconds used to determine when the sensor reading is failed.
const uint32_t    SENSOR_NO_OBSTACLE_US      = 38000UL                        ; //!< ECHO pulse time in microseconds which indicates the absence of sensor readable obstacles.

#endif
/// @}

///
/// \defgroup LCDGroup LCD Constants
/// Constants related to the LCD.
/// @{

// LCD Dimensions
const int32_t     LCD_COLS              = 16                                  ; //!< Number of columns of LCD.
const int32_t     LCD_ROWS              =  2                                  ; //!< Number of rows of LCD.

//LCD Special Characters
const byte        PROGRESS_CHAR         = 1                                   ;                      //!< Index of special character used for progress bar.
const byte        ARROW_UP_CHAR         = 2                                   ;                      //!< Index of special character used for arrow up.
const byte        ARROW_DOWN_CHAR       = 3                                   ;                      //!< Index of special character used for arrow downn.
const int32_t     LCD_CHAR_SIZE         = 8                                   ;                      //!< Size of special character definition array.
const byte        LCD_PROGRESS[LCD_CHAR_SIZE]   = { 0x1F, 0x1F, 0x1F, 0x1F, 0x1F, 0x1F, 0x1F, 0x1F };//!< Definition of special character used for progress bar.
const byte        LCD_ARROW_DOWN[LCD_CHAR_SIZE] = { 0x00, 0x00, 0x00, 0x1F, 0x0E, 0x04, 0x00, 0x00 };//!< Definition of special character used for arrow down.
const byte        LCD_ARROW_UP[LCD_CHAR_SIZE]   = { 0x00, 0x00, 0x04, 0x0E, 0x1F, 0x00, 0x00, 0x00 };//!< Definition of special character used for arrow up.


// LCD pins
const int16_t     RS                    = 3                                   ; //!< LCD's RS digital pin.
const int16_t     E                     = 4                                   ; //!< LCD's E digital pin.
const int16_t     DB4                   = 5                                   ; //!< LCD's DB4 digital pin.
const int16_t     DB5                   = 6                                   ; //!< LCD's DB5 digital pin.
const int16_t     DB6                   = 7                                   ; //!< LCD's DB6 digital pin.
const int16_t     DB7                   = 8                                   ; //!< LCD's DB7 digital pin.
/// @}

///
/// \defgroup ErrCodesGroup Error Codes
/// Error codes used to determine the status in DEBUG mode.
/// @{
const int32_t     ERR_OK                = 0                                   ; //!< All ok. No error occurred.
const int32_t     ERR_SENS              = 1                                   ; //!< Sensor reading error.
const int32_t     ERR_RANGE             = 2                                   ; //!< Sensor reading out of range.
const int32_t     ERR_STAT              = 3                                   ; //!< Consumption calculation error.
const int32_t     ERR_NOISY             = 4                                   ; //!< Noisy error.
/// @}

/// @}

/// \defgroup VarsGroup Global variables
/// @{

/// \defgroup StatusGroup Status flags
/// Status variables.
/// @{
static volatile bool        led_on                    ;  //!< Indicates if LED is turned on (true) or off (false).
static volatile bool        led_status                ;  //!< Indicates if LED is on or blinking (true) or off (false).
static volatile bool        in_debug                  ;  //!< Indicates if the SW is in DEBUG mode (true) or NORMAL mode (false).
static volatile bool        first_measure_done        ;  //!< Establishes if the first measurements used to feed the Median Filter have been done (true) or not (false).
static volatile byte        last_btn_status           ;  //!< Indicates if the button was pressed (HIGH) of not (LOW), to detect long pressure.
static volatile int32_t     err_code                  ;  //!< Contains the current error code (see \ref ErrCodesGroup).
static volatile uint8_t     measure_analysis          ;  //!< Contains the current analysis result.
/// @}

/// \defgroup TimestampsGroup Timestamps
/// The timestamps used to implement non-blocking timers.
/// @{
static volatile uint32_t    timestamp_lcd_on          ;  //!< Timestamp of the last LCD backlight activation in milliseconds.
static volatile uint32_t    timestamp_measurement     ;  //!< Timestamp of the last reading from Median Filter in milliseconds.
static volatile uint32_t    timestamp_last_led_ctrl   ;  //!< Timestamp of the last LED activation in milliseconds.
static volatile uint32_t    timestamp_last_read_dist  ;  //!< Timestamp of the last sensor reading in milliseconds.
static volatile uint32_t    timestamp_btn_press       ;  //!< Timestamp of the last button pressing in milliseconds.
/// @}

/// \defgroup TimingGroup Timings
/// The timing settings (for variable frequency timers).
/// @{
static uint32_t             measure_interval          ;  //!< Contains the current sensor reading period (based on current SW state) in milliseconds.
/// @}


/// \defgroup TankParamsCompGroup Computed tank(s) parameters
/// The computed paramaters based on the currently compiled tank data.
/// @{
static float64_t            tank_capacity             ; //!< The capacity of one tank in liters.
static float64_t            maximum_capacity          ; //!< The capacity of all tanks summed in liters (assume all tanks equals).
/// @}

/// \defgroup ReadingGroup Current reads
/// The last reading status.
/// @{
static uint16_t             number_measures_done      ; //!< The number of measures done during initialization phase.  
static float64_t            percentage                ; //!< The current water level in percentage.
static volatile float64_t   distance                  ; //!< The last distance read from sensor (in centimeters).
static volatile float64_t   previous_liters           ; //!< The previous capacity read in liters.
/// @}

/// @}
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
void loop ( void ) {
  // consumption time management
  stats.updateTime();

  // button management
  manage_button();

  lcd.update_lcd();

  // read current milliseconds passed from boot.
  const uint32_t timestamp_now = millis();
  
  // lcd light timer
  if ( ( timestamp_now - timestamp_lcd_on ) >= LCD_ON_TIME ) {
    turn_off_lcd_light();
  }

  // measurement timer
  if ( ( timestamp_now - timestamp_measurement ) >= measure_interval ) {
    distance = measure_level();
    if ( compare_float ( distance, -1, 0.1 ) == 1 ) {
      // measure error
      print_error();
      delay ( READ_DISTANCE_TIME );

      // skip to next cycle
      return;
    }

    // feed the filter
    ( void ) filter.in ( static_cast < int16_t > ( round_float_value ( distance ) ) );

    // update indicator
    measure_analysis = analyzer.getAnalysis();
  }

  // read distance timer
  if ( ( timestamp_now - timestamp_last_read_dist ) >= READ_DISTANCE_TIME ) {

    // get median value from filter
    distance = filter.out();

    // sanitize the value
    distance = sanitize_data ( 
      distance, 
      SENSOR_DISTANCE_CM, 
      ( WATER_MAX_HEIGHT_CM + SENSOR_DISTANCE_CM ), 
      SENSOR_DISTANCE_CM, 
      ( WATER_MAX_HEIGHT_CM + SENSOR_DISTANCE_CM )
    );

    if ( first_measure_done == true ) {

      // compute the current water volume
      float64_t liters = compute_liters ( distance );
      liters = sanitize_data ( liters, 0.0, maximum_capacity, 0.5, maximum_capacity );

      previous_liters = liters;

      // compute the percentage
      percentage = compute_percentage ( liters );

      // update statistics
      stats.updateConsumption ( static_cast< uint32_t > ( liters ) );

      // update LCD if not in debug
      if ( in_debug == false ) {       
        update_lcd ( percentage, liters );

        // update indicator
        monitorReadings ( );
      }
    }

    // update the timestamp for next value
    timestamp_last_read_dist = timestamp_now;
  }

  // led control timer
  if ( ( timestamp_now - timestamp_last_led_ctrl ) >= LED_CONTROL_TIME ) {
    control_led ( percentage ); 
    timestamp_last_led_ctrl = timestamp_now;
  }

  // go to sleep
  delay ( SLEEP_TIME );
}

/// @}

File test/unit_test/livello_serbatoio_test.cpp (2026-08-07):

#include "livello_serbatoio_test.h"

#include <string>
#include <cstdint>

// dependencies
#include "arduino_types.h"
#include "arduino_stubs.h"
#include "LiquidCrystal.h"
#include "arduinoboard.h"
#include "arduinoboardstub.h"

// --> UUT
#define UNIT_TEST

#define DEBUG  CONF_RELEASE  //<-- release configuration
#define SENSOR SENSOR_HCSR04 //<-- sensor actually used

#define private public
#define volatile

namespace uut {
#include "livello_serbatoio.ino"
}

#undef private
// <--

namespace livelloSerbatoio_tests
{

const uint32_t LivelloSerbatoioTests::TIME_STEP_MS = 100U;

// Unit tests

void LivelloSerbatoioTests::test_PinSetup ( void ) {
    CPPUNIT_ASSERT_EQUAL(static_cast<int16_t>(D2 ), uut::LCD_BUTTON_DPIN   );
    CPPUNIT_ASSERT_EQUAL(static_cast<int16_t>(D3 ), uut::RS                );
    CPPUNIT_ASSERT_EQUAL(static_cast<int16_t>(D4 ), uut::E                 );
    CPPUNIT_ASSERT_EQUAL(static_cast<int16_t>(D5 ), uut::DB4               );
    CPPUNIT_ASSERT_EQUAL(static_cast<int16_t>(D6 ), uut::DB5               );
    CPPUNIT_ASSERT_EQUAL(static_cast<int16_t>(D7 ), uut::DB6               );
    CPPUNIT_ASSERT_EQUAL(static_cast<int16_t>(D8 ), uut::DB7               );
    CPPUNIT_ASSERT_EQUAL(static_cast<int16_t>(D9 ), uut::LCD_LIGHT_DPIN    );
    CPPUNIT_ASSERT_EQUAL(static_cast<int16_t>(D11), uut::TRIG_DPIN         );
    CPPUNIT_ASSERT_EQUAL(static_cast<int16_t>(D12), uut::ECHO_DPIN         );
    CPPUNIT_ASSERT_EQUAL(static_cast<int16_t>(D13), uut::LED_CAPACITY_DPIN );
}

void LivelloSerbatoioTests::test_compute_percentage ( void ) {
    uut::setup(); // to compute maximum capacity

    double liters;

    liters = -DBL_MAX;
    CPPUNIT_ASSERT_DOUBLES_EQUAL(0.0, uut::compute_percentage(liters), 0.1);

    liters = -1.0;
    CPPUNIT_ASSERT_DOUBLES_EQUAL(0.0, uut::compute_percentage(liters), 0.1);

    liters = 0.0;
    CPPUNIT_ASSERT_DOUBLES_EQUAL(0.0, uut::compute_percentage(liters), 0.1);

    liters = 1.0;
    CPPUNIT_ASSERT_DOUBLES_EQUAL(0.1, uut::compute_percentage(liters), 0.1);

    liters = uut::maximum_capacity - 1.0;
    CPPUNIT_ASSERT_DOUBLES_EQUAL(99.9, uut::compute_percentage(liters), 0.1);

    liters = uut::maximum_capacity;
    CPPUNIT_ASSERT_DOUBLES_EQUAL(100.0, uut::compute_percentage(liters), 0.1);

    liters = uut::maximum_capacity + 1.0;
    CPPUNIT_ASSERT_DOUBLES_EQUAL(100.0, uut::compute_percentage(liters), 0.1);

    liters = DBL_MAX;
    CPPUNIT_ASSERT_DOUBLES_EQUAL(100.0, uut::compute_percentage(liters), 0.1);
}

void LivelloSerbatoioTests::test_compute_liters ( void ) {
    double distance;
    //
    distance = -DBL_MAX;
    CPPUNIT_ASSERT_DOUBLES_EQUAL(expected_liters(uut::SENSOR_DISTANCE_CM), uut::compute_liters(distance), 0.1);

    distance = -1.0;
    CPPUNIT_ASSERT_DOUBLES_EQUAL(expected_liters(uut::SENSOR_DISTANCE_CM), uut::compute_liters(distance), 0.1);

    distance = 0.0;
    CPPUNIT_ASSERT_DOUBLES_EQUAL(expected_liters(uut::SENSOR_DISTANCE_CM), uut::compute_liters(distance), 0.1);

    distance = 1.0;
    CPPUNIT_ASSERT_DOUBLES_EQUAL(expected_liters(uut::SENSOR_DISTANCE_CM), uut::compute_liters(distance), 0.1);

    //
    distance = uut::SENSOR_DISTANCE_CM - 1.0;
    CPPUNIT_ASSERT_DOUBLES_EQUAL(expected_liters(uut::SENSOR_DISTANCE_CM), uut::compute_liters(distance), 0.1);

    distance = uut::SENSOR_DISTANCE_CM;
    CPPUNIT_ASSERT_DOUBLES_EQUAL(expected_liters(distance), uut::compute_liters(distance), 0.1);

    distance = uut::SENSOR_DISTANCE_CM + 1.0;
    CPPUNIT_ASSERT_DOUBLES_EQUAL(expected_liters(distance), uut::compute_liters(distance), 0.1);

    //
    distance = uut::TANK_HEIGHT_CM - 1.0;
    CPPUNIT_ASSERT_DOUBLES_EQUAL(expected_liters(distance), uut::compute_liters(distance), 0.1);

    distance = uut::TANK_HEIGHT_CM;
    CPPUNIT_ASSERT_DOUBLES_EQUAL(expected_liters(distance), uut::compute_liters(distance), 0.1);

    distance = uut::TANK_HEIGHT_CM + 1.0;
    CPPUNIT_ASSERT_DOUBLES_EQUAL(0.0, uut::compute_liters(distance), 0.1); //volume can't be negative

    distance = DBL_MAX;
    CPPUNIT_ASSERT_DOUBLES_EQUAL(0.0, uut::compute_liters(distance), 0.1); //volume can't be negative
}

void LivelloSerbatoioTests::test_turn_on_lcd_light  ( void ) {

    harness_getBoard()->harness_setTimePassedFromBoot(rand() % 1000); // any

    uut::turn_on_lcd_light();

    uint32_t uut_timestamp_lcd = uut::timestamp_lcd_on;

    CPPUNIT_ASSERT_EQUAL(HIGH, harness_getBoard()->harness_getPinInternalValue(uut::LCD_LIGHT_DPIN));
    CPPUNIT_ASSERT_EQUAL(harness_getBoard()->harness_getTimePassedFromBoot(), uut_timestamp_lcd);
}

void LivelloSerbatoioTests::test_turn_off_lcd_light  ( void ) {
    uut::turn_off_lcd_light();

    CPPUNIT_ASSERT_EQUAL(LOW, harness_getBoard()->harness_getPinInternalValue(uut::LCD_LIGHT_DPIN));
}

void LivelloSerbatoioTests::test_measure_level ( void ) {
    double level;

    // timeout
    harness_getBoard()->harness_setPulseTime(uut::ECHO_DPIN, 0);

    level = uut::measure_level();

    CPPUNIT_ASSERT_DOUBLES_EQUAL(-1.0, level, 0.1);

    //
    harness_getBoard()->harness_setPulseTime(uut::ECHO_DPIN, static_cast<uint32_t> ( ( uut::SENSOR_MIN_RANGE - 1.0 ) * uut::SENSOR_LSB ) ); // from datasheet ( range = 2 - 400 cm - lsb is 1/58 cm/us )

    level = uut::measure_level();

    CPPUNIT_ASSERT_DOUBLES_EQUAL(-1.0, level, 0.1);

    //
    harness_getBoard()->harness_setPulseTime(uut::ECHO_DPIN, static_cast<uint32_t> ( ( uut::SENSOR_MIN_RANGE ) * uut::SENSOR_LSB ) );

    level = uut::measure_level();

    CPPUNIT_ASSERT_DOUBLES_EQUAL(uut::SENSOR_MIN_RANGE + uut::SENSOR_CALIBRATION, level, 0.1);

    //
    harness_getBoard()->harness_setPulseTime(uut::ECHO_DPIN, static_cast<uint32_t> ( ( uut::SENSOR_MIN_RANGE + 1.0) * uut::SENSOR_LSB ) );

    level = uut::measure_level();

    CPPUNIT_ASSERT_DOUBLES_EQUAL(uut::SENSOR_MIN_RANGE + 1.0 + uut::SENSOR_CALIBRATION, level, 0.1);

    //
    harness_getBoard()->harness_setPulseTime(uut::ECHO_DPIN, static_cast<uint32_t> ( ( uut::SENSOR_MAX_RANGE - 1.0 ) * uut::SENSOR_LSB ) );

    level = uut::measure_level();

    CPPUNIT_ASSERT_DOUBLES_EQUAL(( uut::SENSOR_MAX_RANGE - 1.0 ) + uut::SENSOR_CALIBRATION, level, 0.1);

    //
    harness_getBoard()->harness_setPulseTime(uut::ECHO_DPIN, static_cast<uint32_t> ( ( uut::SENSOR_MAX_RANGE ) * uut::SENSOR_LSB ) );

    level = uut::measure_level();

    CPPUNIT_ASSERT_DOUBLES_EQUAL( ( uut::SENSOR_MAX_RANGE ) + uut::SENSOR_CALIBRATION, level, 0.1);

    //
    harness_getBoard()->harness_setPulseTime(uut::ECHO_DPIN, static_cast<uint32_t> ( ( uut::SENSOR_MAX_RANGE + 1.0 ) * uut::SENSOR_LSB ) );

    level = uut::measure_level();

    CPPUNIT_ASSERT_DOUBLES_EQUAL(-1.0, level, 0.1);

    //
    harness_getBoard()->harness_setPulseTime(uut::ECHO_DPIN, UINT32_MAX );

    level = uut::measure_level();

    CPPUNIT_ASSERT_DOUBLES_EQUAL(-1.0, level, 0.1);
}
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

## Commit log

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2017-09-02 modifica layout lcd - modalità release + aggiunto schema pcb (bozza da completare)
    [scheda.fzz]
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2017-12-26 fix misura litri
    [scheda.fzz]
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2018-01-27 aggiunto messaggio di boot + pdf schema
    [scheda.fzz]
2018-08-07 Taratura sensore + bug fixing - corretto rendering litri - corretti commenti - aumentato tempo campionamento - introdotto arrotondamento distanza a intero più vicino (migliore stabilità misure, preci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
    [livello_serbatoio.ino]
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2018-11-10 introdotto controllo errore per funzione pulseIn
    [livello_serbatoio.ino]
2018-11-10 aggiunto schematico scheda d'interfaccia
    [interfaccia_sensore.fzz]
2018-12-23 Aggiunta compensazione errore del nuovo sensore
    [livello_serbatoio.ino]
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2019-08-11 Aggiornato sketch - Refactory codice - Risoluzione bug (refresh lcd, boot lungo, size variabili) - Aggiunta documentazione - Uniti file in un unico sketch
    [livello_serbatoio.ino]
2019-08-16 bug fix + funzione autotest
    [livello_serbatoio.ino]
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2019-08-21 [da testare] fix statistiche consumo
    [livello_serbatoio.ino]
2019-08-22 [da testare] fix soglia di riempimento in updateConsumption
    [livello_serbatoio.ino]
2020-06-13 Riorganizzazione repository. Rimossa cartella MediaFilter in seguito ad integrazione in un file unico. Aggiunta cartella schemi che include tutti gli schematici realizzati in formato fritzing e pdf.
    [interfaccia_sensore.fzz, scheda.fzz]
2020-06-20 creata test harness per LCD e Serial e stub
    [schema_scheda.fzz]
2020-06-28 Unit test e coverage - Aggiunti unit test per compute_liters, compute_percentage, turn_on_lcd_light, turn_off_lcd_light, measure_level, control_led, sanitize_data - Aggiunto rapporto coverage creato 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
    [compute_liters.ods]
2020-06-29 aggiunti nuovi test per LCD - vari fix sullo sketch - aggiornata coverage - aggiornato makefile
    [livello_serbatoio.ino, livello_serbatoio_test.cpp]
2020-08-02 nuovi test + schematico - bozza schematico per scheda definitiva (realizzato con KiCAD) - implementati nuovi test per MedianFilter - bozza test per StatisticheConsumo - piccole revisioni a sketch (ri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
    [livello_serbatoio_definitiva.kicad_pcb, livello_serbatoio_definitiva.sch, studio_componenti.ods]
2020-08-03 aggiornati unit test - nuovi test per StatisticheConsumo - fix su updateTime in StatisticheConsumo
    [livello_serbatoio.ino, livello_serbatoio_test.cpp]
2020-08-13 nuovi test per funzione loop + modifiche a sketch - inizializzazione oggetti con metodo begin e initialize - fix stampa errore e recovery in seguito ad errore sensore
    [livello_serbatoio.ino, livello_serbatoio_test.cpp]
2020-08-17 fix a schema definitivo e assegnate footprint
    [livello_serbatoio_definitiva.kicad_pcb, livello_serbatoio_definitiva.sch, studio_componenti.ods]
2020-08-18 caricamento prima bozza PCB + piccoli fix a footprint
    [livello_serbatoio_definitiva.kicad_pcb, livello_serbatoio_definitiva.sch]
2020-08-19 modifiche a scheda definitiva - aggiunto footprint LCD di riferimento - modificato schematico per aggiungere connettore ICSP e fori di montaggio a massa - ricollocati connettori - da rivedere colloca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
    [livello_serbatoio_definitiva.kicad_pcb, livello_serbatoio_definitiva.sch, studio_componenti.ods]
2020-08-20 spostato UC in PCB per conflitto con LCD + aggiunto modello 3d Cristallo
    [Crystal.step, crystal.FCStd, livello_serbatoio_definitiva.kicad_pcb]
2020-08-21 riposizionati connettori + auto-routing eseguito con freerouting
    [livello_serbatoio_definitiva.dsn, livello_serbatoio_definitiva.kicad_pcb, livello_serbatoio_definitiva.sch]
2020-08-22 Revisioni a PCB - aggiunta versione a PCB - revisione piste - generato piano di massa - aggiunto gerber
    [livello_serbatoio_definitiva-B_Cu.gbr, livello_serbatoio_definitiva-B_Mask.gbr, livello_serbatoio_definitiva-B_Paste.gbr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]
2020-08-22 prima bozza box da completare
    [box.FCStd, livello_serbatoio_definitiva.kicad_pcb, pcb.FCStd]
2020-08-29 modello 3d completo - lcd - box
    [box.FCStd, lcd.FCStd]
2020-10-11 fix alimentazioni + introduzione coppia differenziale per USB - da rivedere piste USB per match lunghezza/skew/impedenza
    [livello_serbatoio_definitiva-B_Cu.gbr, livello_serbatoio_definitiva-B_Mask.gbr, livello_serbatoio_definitiva-B_Paste.gbr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]
2020-10-18 spostati componenti e fatto nuovo sbroglio
    [livello_serbatoio_definitiva-B_Cu.gbr, livello_serbatoio_definitiva-B_Mask.gbr, livello_serbatoio_definitiva-B_Paste.gbr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]
2020-10-24 rivisto routing di alcune piste
    [livello_serbatoio_definitiva.kicad_pcb]
2020-10-24 modifica traccia usb + rigenerato gerber
    [livello_serbatoio_definitiva-B_Cu.gbr, livello_serbatoio_definitiva-B_Mask.gbr, livello_serbatoio_definitiva-B_Paste.gbr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]
2020-10-25 modificato gerber / disegno 3D box / nuove immagini render aggiunte
    [box.FCStd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]
2020-11-07 nuovo routing + BOM + aggiornamento lista componenti
    [livello_serbatoio_definitiva.sch]
2020-11-08 fix a scheda - corrette footprint (adeguate a componenti in possesso) - nuovo routing e layout scheda - aggiunto logo - aggiornato gerber
    [ACP470.step, CUI_DEVICES_TB001-500-04BE.step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]
2020-11-14 aggiunta protezione ESD - nuovo routing usb - nuove immagini pcb
    [CUI_DEVICES_TB001-500-04BE.step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]
2020-11-15 allineamento modello 3d + fix minori pcb - aggiornato modello box - aggiunto logo a box - nuovi modelli 3d fusibile e trimmer - aggiornato sch per fusibile - aggiornato pcb - nuove immagini + doc pro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
    [ACP470.step, CUI_DEVICES_TB001-500-P04GR.step, MF-MSMF050-2.FCStd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]
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2020-11-21 esportati pin per espandibilità
    [livello_serbatoio_definitiva-B_Cu.gbr, livello_serbatoio_definitiva-B_Mask.gbr, livello_serbatoio_definitiva-B_Paste.gbr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]
2020-11-22 revisioni minime a pcb
    [livello_serbatoio_definitiva-B_Cu.gbr, livello_serbatoio_definitiva-B_Mask.gbr, livello_serbatoio_definitiva-B_Paste.gbr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]
2020-11-23 fix footprint trimmer - aggiornato pcb
    [livello_serbatoio_definitiva-B_Cu.gbr, livello_serbatoio_definitiva-B_Mask.gbr, livello_serbatoio_definitiva-B_Paste.gbr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]
2020-11-28 aggiornamento PCB - ridefinite filled zone - stondati bordi - cambiato connettore per espansione - rimosse via per GND
    [livello_serbatoio_definitiva-B_Cu.gbr, livello_serbatoio_definitiva-B_Mask.gbr, livello_serbatoio_definitiva-B_Paste.gbr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]
2020-11-29 piccole revisioni PCB - spostate alcune piste per maggiore copertura filled zone - rivisti alcuni parametri per manufacturing (dimensione scritte, S/N) - rimosse alcune vie e piste per piano GND inut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
    [livello_serbatoio_definitiva-B_Cu.gbr, livello_serbatoio_definitiva-B_Mask.gbr, livello_serbatoio_definitiva-B_Paste.gbr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]
2020-11-30 revisionata connessione DTR logica reset - revisionato wiring DTR - aggiornato PCB - ricreato gerber
    [livello_serbatoio_definitiva-B_Cu.gbr, livello_serbatoio_definitiva-B_Mask.gbr, livello_serbatoio_definitiva-B_Paste.gbr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]
2020-12-01 revisione piste circuito reset - spostata pista DTR - spostato pulsante - aggiornato piano di massa - rimossa una via su DTR
    [livello_serbatoio_definitiva-B_Cu.gbr, livello_serbatoio_definitiva-B_Mask.gbr, livello_serbatoio_definitiva-B_Paste.gbr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]
2020-12-04 aggiunto ulteriore connettore per espansioni - riviste piste - rivisti piani di massa
    [livello_serbatoio_definitiva-B_Cu.gbr, livello_serbatoio_definitiva-B_Mask.gbr, livello_serbatoio_definitiva-B_Paste.gbr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]
2020-12-05 revisione pcb - fix misure lcd - spostate alcune piste
    [livello_serbatoio_definitiva-B_Cu.gbr, livello_serbatoio_definitiva-B_Mask.gbr, livello_serbatoio_definitiva-B_Paste.gbr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]
2020-12-06 aumentate dimensioni track +5V - rivisto layout di alcune piste - aggiunti commenti su layout
    [livello_serbatoio_definitiva-B_Cu.gbr, livello_serbatoio_definitiva-B_Mask.gbr, livello_serbatoio_definitiva-B_Paste.gbr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]
2020-12-08 spostato LCD e rifatto modello box - LCD centrato su LCD - revisione layout - nuovo modello box (box + coperchio + pulsante + assembly scheda e lcd) - aggiornate immagini prototipo - creati file stl 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
    [assembly.FCStd, box.FCStd, box_part.FCStd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]
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2020-12-20 fix mesh box
    [assembly.FCStd, box_part.FCStd, box_print.stl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]
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2020-12-22 piccoli fix a PCB
    [livello_serbatoio_definitiva-B_Cu.gbr, livello_serbatoio_definitiva-B_Mask.gbr, livello_serbatoio_definitiva-B_Paste.gbr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]
2020-12-27 aggiunte piazzole CTS/RTS + aggiunte etichette a pin digitali - rivisto gerber - rivista footprint oscillatore
    [livello_serbatoio_definitiva-B_Cu.gbr, livello_serbatoio_definitiva-B_Mask.gbr, livello_serbatoio_definitiva-B_Paste.gbr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]
2020-12-28 fix serigrafie PCB - generato gerber - caricamento test seriale
    [livello_serbatoio_definitiva-B_Cu.gbr, livello_serbatoio_definitiva-B_Mask.gbr, livello_serbatoio_definitiva-B_Paste.gbr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]
2020-12-30 caricamento prototipo espansione - schema elettrico + pcb - assemblaggio 3d con scheda di espansione
    [assembly_exp.FCStd, box_part.FCStd, coperchio.FCStd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]
2021-02-13 modifica per seriale - aggiunto elettrolitico per alimentazione - fix test seriale
    [livello_serbatoio_definitiva-B_Cu.gbr, livello_serbatoio_definitiva-B_Mask.gbr, livello_serbatoio_definitiva-B_Paste.gbr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]
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2021-05-23 disconnesso pin reset di ft232
    [livello_serbatoio_definitiva.kicad_pcb, livello_serbatoio_definitiva.sch]
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2021-08-10 piccoli fix (commenti, formattazione)
    [livello_serbatoio.ino]
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2021-08-12 fix su visualizzazione errore + unit test loop e bottone
    [livello_serbatoio.ino, livello_serbatoio_test.cpp]
2021-08-12 fix visualizzazione 'menu' su display
    [livello_serbatoio.ino]
2021-08-12 fix flickering LCD in visualizzazione menu
    [livello_serbatoio.ino]
2021-08-13 fix lcd backlight in modalità maintenance
    [livello_serbatoio.ino]
2021-08-13 fix visualizzazione uscita menu
    [livello_serbatoio.ino]
2021-08-17 Fix + doc - [fix] backlight non funzionante in Manutenzione - [fix] lcd non funzionante con LcdHelper - [fix] doc doxygen
    [livello_serbatoio.ino]
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2023-08-11 v0.9: fix dimensioni serbatoio
    [livello_serbatoio.ino]
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2024-04-26 scheda rev.D - rimosse resistenze RX/TX seriale - aggiustamento label
    [livello_serbatoio_definitiva.kicad_pcb, livello_serbatoio_definitiva.kicad_sch]
2024-05-05 scheda rev. D - applicate revisioni - allineati vincoli a capability jlc - adattata scheda prototipo
    [livello_serbatoio_definitiva-B_Cu.gbr, livello_serbatoio_definitiva-B_Mask.gbr, livello_serbatoio_definitiva-B_Paste.gbr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]
2025-08-16 fix lettura stato riempimento serbatoio
    [livello_serbatoio.ino]
2025-08-17 fix misura tendenza - aggiornato framework per print float su lcd - abbassata freq letture HF - cambiata print debug
    [livello_serbatoio.ino]
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2025-08-23 revisioni pcb (rimosse violazione jlcpcb) aggiunti stl per case e coperchio da fusion360
    [Case.stl, Coperchio.stl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]
2025-08-25 aggiunta nuova revisione scheda con ch340 al posto di ft232rl
    [ACP470.step, CUI_DEVICES_TB001-500-P04GR.step, Crystal.step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]
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2026-06-28 fix qt projects - auto deploy - uso diretto di livello_serbatoio.ino
    [livello_serbatoio_test.cpp]
2026-08-07 fix gestione indicatore trend in modalità debug
    [livello_serbatoio.ino]
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
